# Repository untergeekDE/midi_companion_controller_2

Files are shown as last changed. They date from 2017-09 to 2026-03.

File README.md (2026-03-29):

# MIDI Companion Controller V3.0

A MIDI companion controller with two analog wheels (pitch bend + mod wheel), two buttons, a footswitch, two LEDs, and a 128x64 OLED display. Runs on a Raspberry Pi Pico 2 (RP2350) with CircuitPython 10.x.

## Features

- **Two analog wheels**: Pitch bend (centered) and modulation (CC1)
- **Two buttons + footswitch**: Configurable as CC, NoteOn/Off, Aftertouch, or Off
- **OLED display**: Shows MIDI channel, wheel values, firmware version
- **DIN MIDI In/Out**: Standard 5-pin DIN via UART + optocoupler circuit
- **USB MIDI**: Appears as a USB MIDI device to a connected computer/DAW
- **USB Host** (optional): MAX3421E breakout for connecting USB MIDI devices (e.g., Launchpad)
- **MIDI merge engine**: Routes messages between all inputs and outputs with echo prevention
- **On-device menu**: Configure CC assignments, MIDI channel, thru, deadband, calibration
- **Watchdog**: Auto-resets if the main loop hangs (enabled after first successful iteration)

## Hardware

- **Board**: Raspberry Pi Pico 2 W (RP2350, CircuitPython 10.1.4)
- **Display**: SSD1306 128x64 I2C OLED at 0x3C
- **MIDI DIN**: Optocoupler circuit or Adafruit MIDI FeatherWing
- **USB Host**: Adafruit MAX3421E breakout (optional)

### Pin Assignments

| GPIO | Function | Notes |
|---|---|---|
| GP0 | Button A | Menu / navigation, INPUT_PULLUP |
| GP1 | Button B | Confirm / set, INPUT_PULLUP |
| GP2 | LED 1 | MIDI input activity |
| GP3 | LED 2 | MIDI output activity |
| GP4 | UART TX | DIN MIDI Out, 31250 baud |
| GP5 | UART RX | DIN MIDI In, 31250 baud |
| GP13 | Footswitch | 1/4" jack, INPUT_PULLUP |
| GP14 | USB Host INT | MAX3421E (optional) |
| GP16 | SPI MISO | MAX3421E (optional) |
| GP18 | SPI CLK | MAX3421E (optional) |
| GP19 | SPI MOSI | MAX3421E (optional) |
| GP20 | I2C SDA | OLED |
| GP21 | I2C SCL | OLED |
| GP22 | USB Host CS | MAX3421E (optional) |
| GP26/A0 | Wheel A | Pitch bend (analog) |
| GP27/A1 | Wheel B | Modulation (analog) |

See [HARDWARE_PICO.md](HARDWARE_PICO.md) for detailed documentation.

## Installation

1. Install CircuitPython 10.x on the Pico 2
2. Copy `circuitpython/` contents to the CIRCUITPY drive
3. Install Adafruit libraries:
   ```bash
   pip install circup
   circup install adafruit_midi adafruit_debouncer adafruit_ticks adafruit_displayio_ssd1306 adafruit_display_text
   ```
4. For USB Host mode, also: `circup install adafruit_usb_host_midi max3421e`

## Developer Mode

Hold **Button A** (GP0) during power-on to enter dev mode. This keeps the CIRCUITPY drive writable from USB for editing files. In normal mode, CircuitPython owns the filesystem for writing config.json.

## Testing

Host-side integration tests communicate with the Pico over USB MIDI and serial:

```bash
pip install -r tests/requirements.txt
# Automated tests (device connected, normal mode):
MIDI_DEVICE_NAME=CircuitPython pytest tests/ -v --ignore=tests/test_wheels_buttons.py
# Interactive hardware test:
MIDI_DEVICE_NAME=CircuitPython python3 tests/test_hardware.py
```

See [tests/README.md](tests/README.md) for details.

## Known Issues and Status (2026-03-29)

### Verified Working
- Button A (GP0) and Button B (GP1) — confirmed via GPIO probe
- LED 1 (GP2) and LED 2 (GP3) — confirmed via LED test
- OLED display — working with CP10 `i2cdisplaybus.I2CDisplayBus`, rotation=0
- USB MIDI device — enumeration, send, receive all working
- DIN UART loopback — raw bytes sent on GP4/TX received on GP5/RX through DIN connectors (optocoupler circuit functional)
- Config persistence — load, save, validation, corrupt detection all working
- Wheel B (mod wheel) — sends CC1, values 0-127, display shows decimal
- Wheel A (pitch bend) — sends PitchBend, calibrated, display shows signed values

### Known Issues

| Issue | Status | Details |
|---|---|---|
| **DIN MIDI not reaching external synth** | **Open** | UART loopback through DIN connectors works (raw bytes verified). USB→DIN routing via merge engine sends data, but external synthesizer does not respond. Possible causes: cable pin assignment (DIN-5 pins 4/5), signal level/polarity through optocoupler, or synth-specific issue. Needs oscilloscope verification. |
| **Wheel B ADC jitter** | **Open** | Mod wheel oscillates ±2 values at rest (e.g., 44-46), causing continuous CC output and LED B staying on. Root cause: ADC noise on the potentiometer. Mitigations: increase deadband, add 100nF capacitor across pot, or implement hysteresis filter in software. |
| **Watchdog crash-loop** | **Fixed** | Watchdog now only activates after the first fully successful loop iteration. If code.py crashes on startup, the device stays at the REPL instead of resetting endlessly. |
| **CircuitPython 10 API changes** | **Fixed** | `displayio.I2CDisplay` → `i2cdisplaybus.I2CDisplayBus`, `watchdog.WatchdogMode` → `watchdog.WatchDogMode`, `PitchBend` expects unsigned 0-16383. |

### Hardware Test Results

```
Buttons:  GP0 (A) ✓  GP1 (B) ✓
LEDs:     GP2 ✓  GP3 ✓
UART:     GP4 TX → DIN OUT → DIN IN → GP5 RX: loopback ✓
Display:  SSD1306 I2C 0x3C: ✓ (rotation=0)
USB MIDI: enumeration ✓, send ✓, receive ✓
DIN→Synth: ✗ (needs investigation)
```

## Project Structure

```
circuitpython/
  boot.py              # Filesystem + USB setup
  code.py              # Main loop (v2.0.0)
  config.json          # Persistent config (JSON)
  lib/
    config.py          # ConfigManager with validation
    menu.py            # On-device config menu
    calibration.py     # Wheel calibration (30s timeout)
    midi_merge.py      # N→M merge with echo prevention
    hardware/
      pins.py          # Pin definitions (single source of truth)
      wheels.py        # Analog wheel with deadband
      buttons.py       # Debounced buttons with double-click
      leds.py          # LEDs with 50ms min on-time
      display.py       # SSD1306 OLED via displayio
      midi_uart.py     # DIN MIDI via UART
      midi_usb_device.py  # Native USB MIDI
      midi_usb_host.py    # MAX3421E USB Host (optional)
tests/
  conftest.py          # MIDI + serial REPL fixtures
  test_hardware.py     # Interactive hardware diagnostic
  test_midi_device.py  # USB MIDI enumeration tests
  test_config.py       # Config persistence tests
  test_error_recovery.py  # Corrupt config, MIDI flood
  test_wheels_buttons.py  # Manual input tests
```

## History

- **V1.0**: Arduino + DangerShield (original prototype)
- **V2.0**: Teensy 3.2 + custom hardware (`src/main.cpp` — legacy, see [BUGLIST_TEENSY.md](BUGLIST_TEENSY.md))
- **V3.0**: Raspberry Pi Pico 2 + CircuitPython 10 (this version)

## License

CC-BY — untergeek.de

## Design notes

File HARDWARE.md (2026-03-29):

# Hardware Documentation

MIDI companion controller with two analog wheels (pitch bend + mod wheel), two buttons, a footswitch, two LEDs, and a 128x64 OLED display. Two hardware implementations exist.

See the implementation-specific files:

- [HARDWARE_TEENSY.md](HARDWARE_TEENSY.md) — Teensy 3.2 (`src/main.cpp`)
- [HARDWARE_PICO.md](HARDWARE_PICO.md) — Raspberry Pi Pico 2 (`circuitpython/`)

Fritzing schematic (Teensy): `midicompanion2-0.fzz`

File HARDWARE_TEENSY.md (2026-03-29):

# Hardware Documentation — Teensy 3.2

Implementation: `src/main.cpp`

## Board
- **MCU**: Teensy 3.2 (MK20DX256, ARM Cortex-M4, 72 MHz)
- **USB**: Native USB MIDI (via Teensyduino)
- **ADC**: 10-bit (0-1023)

## Pin Assignments

| Pin | Type | Function | Notes |
|-----|---|---|---|
| A22 | Analog | Wheel A (Pitch Bend) | Left wheel |
| A23 | Analog | Wheel B (Modulation) | Right wheel |
| D17 | Digital | Button A | Menu / navigation, INPUT_PULLUP |
| D15 | Digital | Button B | Confirm / set, INPUT_PULLUP |
| D13 | Digital | Button C (Footswitch) | 1/4" jack, INPUT_PULLUP |
| D16 | Digital | LED 1 | MIDI input activity |
| D14 | Digital | LED 2 | MIDI output activity |
| D4 | Digital | OLED Reset | SSD1306 reset pin |
| Serial1 TX/RX | UART | DIN MIDI In/Out | 31,250 baud |
| I2C (Wire) | I2C | OLED Display | SSD1306 128x64 |

## Components
- **Display**: SSD1306 128x64 I2C OLED (custom `OLED_I2C_128x64_Monochrome` library)
- **MIDI**: DIN-5 In/Out via Serial1 UART at 31,250 baud
- **Buttons**: Momentary pushbuttons, active low (INPUT_PULLUP)
- **Footswitch**: 1/4" TRS jack, active low (INPUT_PULLUP)
- **LEDs**: Standard LEDs, HIGH = on
- **Wheels**: Linear potentiometers, ~256 ADC count range

## Wheel Calibration Defaults
| Parameter | Wheel A (Pitch) | Wheel B (Mod) |
|---|---|---|
| Center | 658 | 909 |
| Delta | 517 | 700 |

## EEPROM Memory Map (32 bytes)

| Byte(s) | Purpose | Default |
|---|---|---|
| 0 | Checksum (additive sum) | — |
| 1 | Wheel A CC (0x80 = pitch bend) | 0x80 |
| 2 | Wheel B CC (0x80 = pitch bend) | 1 (CC1 Mod) |
| 3 | Button A CC (0x80 = aftertouch) | 64 (Sustain) |
| 4 | Button B CC (0x80 = aftertouch) | 0x80 |
| 5 | Button C (Footswitch) CC | 64 (Sustain) — code default; `#define CCBUTTON_C 66` is unused |
| 6-7 | Wheel A delta (calibration) | 517 |
| 8-9 | Wheel A center | 658 |
| 10-11 | Wheel A Hi (unused) | 256 |
| 12-13 | Wheel B delta | 700 |
| 14-15 | Wheel B center | 909 |
| 16-17 | Wheel B Hi (unused) | 256 |
| 18 | TX MIDI channel (1-16) | 1 |
| 19 | Aftertouch default value | 64 |
| 20 | MIDI Thru on/off | 0 |
| 21 | Deadband width (0-63) | 10 |
| 22-31 | Unused | 0 |

## Schematic

Fritzing file: `midicompanion2-0.fzz`

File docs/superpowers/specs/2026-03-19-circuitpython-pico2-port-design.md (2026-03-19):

# MIDI Companion Controller 2 — CircuitPython Port for Raspberry Pi Pico 2

## Overview

Port of the Teensy 3.2-based MIDI companion controller to Raspberry Pi Pico 2 (RP2350) running CircuitPython. The controller merges MIDI input from a Novation Launchpad Pro 3 (via USB Host) and local controls (wheels, buttons, footswitch) with optional DIN MIDI Thru, outputting a merged MIDI stream over DIN MIDI to a Roland SE-02 synthesizer.

### Key Changes from Original

- Teensy 3.2 → Raspberry Pi Pico 2 (RP2350)
- C++ (Arduino/Teensyduino) → CircuitPython 9.x
- Single 790-line file → modular library with HAL + feature modules
- EEPROM with checksum → JSON config file on CIRCUITPY flash
- Custom OLED library → standard adafruit_displayio_ssd1306
- USB-MIDI device output → removed (DIN-only output). `boot.py` disables USB MIDI device and USB HID to free the USB stack. The Pico does not appear as a MIDI device to a connected computer.
- New: USB Host input via MAX3421E SPI breakout for Launchpad Pro 3
- Deliberate behavior change: channel auto-tracking from DIN input is removed. The controller always sends on the configured `tx_channel`. (The original Teensy code would adopt the channel of any incoming MIDI message.)

## Signal Flow

```
┌─────────────────────┐     ┌──────────────────┐
│  Launchpad Pro 3    │     │  DIN MIDI In      │
│  (USB Host/MAX3421E)│     │  (UART RX)        │
└────────┬────────────┘     └────────┬───────────┘
         │ all MIDI data              │ any MIDI
         │ (no filtering)            │ data
         ▼                           ▼
    ┌─────────────────────────────────────┐
    │            MidiMerge                │
    │  ┌───────────────────────────┐      │
    │  │ inject() ← local events  │      │
    │  │  · Pitch Bend (Wheel A)  │      │
    │  │  · Mod Wheel (Wheel B)   │      │
    │  │  · CC/ATO (Buttons)      │      │
    │  └───────────────────────────┘      │
    └────────────────┬────────────────────┘
                     │ merged
                     │ MIDI stream
                     ▼
            ┌─────────────────┐
            │  DIN MIDI Out   │
            │  (UART TX)      │
            │  → Roland SE-02 │
            └─────────────────┘
```

## Project Structure

```
circuitpython/
  boot.py                       # Runs before code.py: remounts filesystem writable, disables USB MIDI/HID
  code.py                       # Entry point: setup + main loop (wiring only, no logic)
  config.json                   # Persisted configuration on CIRCUITPY flash
  lib/
    hardware/
      pins.py                   # Pin definitions as central constants (only place GPIOs are defined)
      wheels.py                 # AnalogWheel: read, calibration, deadband
      buttons.py                # DebouncedButton: debounce, fell/rose, double-click detection
      leds.py                   # StatusLED: on/off
      display.py                # OledDisplay: SSD1306 via displayio
      midi_uart.py              # UartMidi: DIN MIDI In + Out over UART
      midi_usb_host.py          # UsbHostMidi: MAX3421E via adafruit_usb_host_midi
    midi_merge.py               # MidiMerge: N inputs merged onto M outputs
    config.py                   # ConfigManager: JSON read/write, defaults, validation
    menu.py                     # OnDeviceMenu: menu structure, navigation, value editing
    calibration.py              # WheelCalibration: interactive calibration, saves to config
```

The existing Teensy version remains unchanged in `src/`.

## Hardware Modules

### pins.py

Pure constants file. All GPIO assignments in one place. All other modules import from here. Also defines SPI pins for the MAX3421E.

### wheels.py — AnalogWheel

```python
wheel = AnalogWheel(pin, mode="pitch_bend", deadband=10)
wheel.calibrate(center=658, delta=517)
value = wheel.read()  # → int: -8192..8191 (pitch_bend) or 0..127 (cc)
wheel.changed         # → bool: True if value changed since last read
wheel.value           # → int: last read value
```

- Wraps `analogio.AnalogIn` with calibration offset and deadband logic.
- Mode (`pitch_bend` vs `cc`) determines centered (signed) or uncentered (unsigned) reading.
- **Pitch bend mode** returns 14-bit values (-8192..8191) as expected by `adafruit_midi.PitchBend`. The original code reads -128..127 and multiplies by 64; this module does the scaling internally.
- **CC mode** returns 7-bit values (0..127).
- Calibration uses `center` for pitch bend mode (centered wheel) and `delta` for CC mode (uncentered wheel), matching the original behavior (see original lines 725-726).
- `deadband` is a global setting shared by both wheels (loaded from `config.deadband`).
- Same algorithm as original `readWheel()`, encapsulated as a class.

### buttons.py — DebouncedButton

```python
btn = DebouncedButton(pin, debounce_ms=10, double_click_ms=250)
btn.update()
btn.fell              # → bool: just pressed
btn.rose              # → bool: just released
btn.double_click      # → bool: double-click detected
```

- Uses `adafruit_debouncer` instead of Bounce2.
- Double-click detection built in (timestamp-based, like original).
- `fell` = button pressed (active low with INPUT_PULLUP), `rose` = button released. All buttons use the same polarity convention. The main loop determines what MIDI value to send on fell vs. rose (e.g., CC 127 on fell, CC 0 on rose).

### leds.py — StatusLED

```python
led = StatusLED(pin)
led.on()
led.off()
```

- Minimal wrapper around `digitalio.DigitalInOut`.
- LED1 = MIDI input activity, LED2 = MIDI output activity.

### display.py — OledDisplay

```python
disp = OledDisplay(i2c)
disp.show_workscreen(channel=1, wheel_a=0, wheel_b=0)
disp.show_text(row, col, text, inverted=False)
disp.show_hex(row, col, value)
disp.clear()
disp.update_values(wheel_a=0, wheel_b=0)
```

- Uses `displayio` + `adafruit_displayio_ssd1306` + `adafruit_display_text`.
- Abstracts workscreen, menu, and calibration screen rendering.
- Font size handling internal (replaces global `fontsize` variable from original).
- Display is rotated 180 degrees (matching original `oled.rotateDisplay180()`) — configured in `displayio` initialization.

### midi_uart.py — UartMidi

```python
midi = UartMidi(uart_tx_pin, uart_rx_pin)
msg = midi.receive()                        # → adafruit_midi message or None
midi.send(msg)                              # Send any MIDI message
midi.send_cc(cc, value, channel)
midi.send_pitch_bend(value, channel)
midi.send_aftertouch(value, channel)
```

- Uses `adafruit_midi` over `busio.UART` at 31250 baud.
- Shared message format with `UsbHostMidi` (both use `adafruit_midi` message types).

### midi_usb_host.py — UsbHostMidi

```python
usb_midi = UsbHostMidi(spi, cs_pin)
msg = usb_midi.receive()  # → adafruit_midi message or None
```

- MAX3421E over SPI via `adafruit_max3421e` + `adafruit_usb_host_midi`.
- Same message interface as `UartMidi`.
- Receive only (Launchpad sends to controller).
- **Hot-plug handling:** `receive()` returns `None` if no device is connected. The module handles enumeration failures and disconnection gracefully — no crash, no error on display, just no input from that source. On reconnection, the device is re-enumerated automatically.
- No device filtering: any USB MIDI device is accepted, not just the Launchpad.

## MidiMerge

```python
merge = MidiMerge(
    inputs=[uart_midi_in, usb_host_midi],
    outputs=[uart_midi_out],
    thru_enabled=False
)
merge.process()           # Read all inputs, forward to outputs
merge.inject(msg)         # Inject local messages (wheels/buttons)
merge.had_input           # → bool: True if any input was received this cycle
```

### Merge Rules

- **USB Host input** (Launchpad): always forwarded to outputs unmodified. No filtering, no channel remapping.
- **DIN MIDI input:** only forwarded when `thru_enabled` is True. When `thru_enabled` is False, DIN input is ignored (not merged). This matches the original behavior where MIDI Thru is a configurable on/off toggle.
- Local events (wheels, buttons) are injected via `inject()` and always sent on `tx_channel`.
- `process()` called once per main loop iteration.
- Order per loop: read inputs → inject local events → send all.

## Configuration System

### config.json

```json
{
  "midi": {
    "tx_channel": 1,
    "thru_enabled": false
  },
  "wheel_a": {
    "mode": "pitch_bend",
    "cc_number": null,
    "calibration": {
      "delta": 517,
      "center": 658
    }
  },
  "wheel_b": {
    "mode": "cc",
    "cc_number": 1,
    "calibration": {
      "delta": 700,
      "center": 909
    }
  },
  "button_a": {
    "mode": "cc",
    "cc_number": 64
  },
  "button_b": {
    "mode": "aftertouch",
    "aftertouch_value": 64
  },
  "footswitch": {
    "mode": "cc",
    "cc_number": 66
  },
  "deadband": 10
}
```

### ConfigManager

```python
config = ConfigManager("config.json")
config.load()                          # Read file, fall back to built-in defaults
config.save()                          # Write current state to file
config.get("midi.tx_channel")          # → value
config.set("midi.tx_channel", 2)       # Update in memory
```

- Falls back to built-in defaults when file is missing or corrupt.
- Validates value ranges on load (channel 1-16, CC 0-127, etc.).
- Replaces EEPROM+checksum system entirely.
- **Filesystem write access:** `boot.py` remounts the CIRCUITPY filesystem as writable by CircuitPython code (`storage.remount("/", readonly=False)`). Side effect: the drive becomes read-only when connected to a computer via USB. To edit `config.json` or `code.py` from a PC, hold a designated button during boot to skip the remount (keeping the filesystem writable by USB instead).

### Interaction with On-Device Menu

1. On startup: `config.load()` reads the file.
2. Menu changes: `config.set()` updates values in memory.
3. On menu exit: `config.save()` writes everything back to JSON.

## Menu System

### OnDeviceMenu

```python
menu = OnDeviceMenu(display, config, wheels, buttons)
menu.enter()    # Blocks until menu is exited
```

**Trigger:** Double-click on Button A.

**Note:** Menu and calibration are blocking — MIDI processing stops while the menu is active. This matches the original behavior and is a deliberate choice (menu interaction is brief and infrequent).

**Navigation** (same as original):
- Button A: next option
- Button B: set/confirm value
- Wheel B: scroll value
- "X" top right: exit menu

**Menu Options:**

| Option | Range | Description |
|---|---|---|
| Wheel A | CC 0-127 / PWH | CC number or pitch bend |
| Wheel B | CC 0-127 / PWH | CC number or pitch bend |
| Button A | CC 0-127 / ATO | CC number or aftertouch |
| Button B | CC 0-127 / ATO | CC number or aftertouch |
| Footswitch | CC 0-127 / ATO | CC number or aftertouch |
| TX Channel | 1-16 | MIDI transmit channel |
| Thru | ON/OFF | DIN MIDI Thru |
| ATO Value | 0-127 | Aftertouch default value |
| Deadband | 0-63 | Deadband width |
| Calibrate | GO | Starts calibration routine |

## Calibration

### WheelCalibration

```python
cal = WheelCalibration(display, wheels, buttons, config)
cal.run()       # Blocks: shows instructions, waits for button, measures, saves
```

**Sequence** (same as original):
1. Display shows "Release Pitch Wheel / Return Mod Wheel to zero / Press button"
2. User presses Button B
3. Read current analog values as center/delta
4. Write values to ConfigManager
5. Show confirmation, wait for button press
6. Return to menu

## Main Loop (code.py)

`code.py` contains only wiring and the main loop — no business logic. All domain logic lives in the modules.

```python
# 1. SETUP
config = ConfigManager("config.json")
config.load()

# Initialize all hardware via pin constants
# Initialize MidiMerge with uart_midi + usb_host_midi inputs, uart_midi output
# Initialize OnDeviceMenu
# Show workscreen

# 2. MAIN LOOP
while True:
    # Update all buttons
    # Check for double-click → enter menu
    # merge.process() — read all MIDI inputs, forward
    # LED1 blink on MIDI input
    # Read wheels, inject changed values via merge.inject()
    # Read buttons, inject fell/rose events via merge.inject()
    # LED2 blink on MIDI output
    # Update display (only on value changes)
    # Turn off LEDs at end of loop
```

The loop is synchronous — CircuitPython on RP2350 is fast enough for real-time MIDI.

## Dependencies

### Adafruit CircuitPython Libraries (from Bundle)

| Library | Purpose |
|---|---|
| `adafruit_midi` | MIDI message types + UART MIDI |
| `adafruit_usb_host_midi` | USB Host MIDI via MAX3421E |
| `adafruit_max3421e` | MAX3421E SPI driver |
| `adafruit_debouncer` | Button debouncing |
| `adafruit_displayio_ssd1306` | SSD1306 OLED driver |
| `adafruit_display_text` | Text rendering on displayio |
| `adafruit_bitmap_font` | Font sizes (optional) |

### Built-in CircuitPython Modules

| Module | Purpose |
|---|---|
| `board`, `digitalio`, `analogio` | GPIO |
| `busio` | I2C, SPI, UART |
| `displayio` | Display framework |
| `json` | Config file parsing |
| `time` | Timing (double-click, LED blink) |
| `usb_host` | USB Host base functionality |

### Target Platform

- **Board:** Raspberry Pi Pico 2 or Pico 2 W (RP2350)
- **CircuitPython:** 9.x (stable for RP2350, USB Host support)
- **USB Host Hardware:** Adafruit MAX3421E USB Host Breakout (SPI)

### Additional Hardware

- SSD1306 128x64 I2C OLED (same as original)
- MIDI DIN In/Out circuit — either:
  - Custom optocoupler circuit (same as original), OR
  - Adafruit MIDI FeatherWing (plug-and-play alternative, provides DIN In + Out via UART)
- Potentiometers/wheels, buttons, footswitch, LEDs (same as original)

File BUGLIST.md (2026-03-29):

# Bug List & Known Weaknesses

See the implementation-specific files:

- [BUGLIST_TEENSY.md](BUGLIST_TEENSY.md) — Teensy 3.2 bugs and weaknesses
- [BUGLIST_PICO.md](BUGLIST_PICO.md) — CircuitPython / Pico 2 bugs and weaknesses

Last reviewed: 2026-03-29, iteration 7 (final)

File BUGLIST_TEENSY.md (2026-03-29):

# Bug List — Teensy 3.2 (`src/main.cpp`)

Last reviewed: 2026-03-29, iteration 5 (Teensy review complete — further iterations focused on Pico only)

## Bugs

| # | Severity | Location | Description |
|---|---|---|---|
| T1 | **Critical** | Lines 743, 771 | **CC modulo is wrong**: `EEPROM[1] % 0x7f` uses 127, not 128. CC value 127 wraps to 0. Should be `% 128` or bounds-check to 0-127. |
| T2 | **Critical** | Lines 656, 688, 708 | **Aftertouch never triggers**: `EEPROM[3] > 0x80` should be `>= 0x80`. The aftertouch sentinel is 0x80 (128), but `128 > 128` is false. The aftertouch branch is unreachable for all three buttons. Instead, CC 128 is sent (out of MIDI spec). |
| T3 | **High** | Lines 695, 715 | **Button B/C CC polarity inverted**: Button A uses `!button1.read() * 127` (pressed=127, released=0), but buttons B and C use `button2.read() ? 127 : 0` (pressed=0, released=127). CC messages are backwards — sustain activates on release, not press. |
| T4 | **Medium** | Line 737 | **Pitch bend scaling short of full range**: `value * 64` gives max 127x64=8128, but MIDI pitch bend max is 8191. Positive range is ~0.8% short of full scale. |

## Weaknesses

| # | Severity | Location | Description |
|---|---|---|---|
| T5 | Medium | Lines 636-647 | **Auto-adopts incoming MIDI channel**: `MidiTxCh = MidiRxCh` silently changes the TX channel to match any incoming message. |
| T6 | Medium | Lines 612-761 | **LED blinks invisible**: LEDs turn on/off within a single loop iteration (<2ms). No minimum on-time. |
| T7 | Medium | Line 417 | **Menu has no timeout**: `for(;;)` blocks indefinitely. No watchdog or auto-exit. |
| T8 | Medium | Lines 378-379 | **Calibration assumes ~256 ADC range**: `center = delta + 128` hardcoded. |
| T9 | Medium | Lines 653, 685, 705 | **Buttons send CC on every update**: RefreshFlag causes continuous CC sends, not just on edges. |
| T10 | Low | Line 500 | **Menu calls itself recursively**: `calibrate()` -> `menu()` recursive. Stack grows per calibration. |
| T11 | Low | Line 280 | **Footswitch default CC mismatch**: `nvrInits[5] = 64` but `#define CCBUTTON_C 66` unused. |
| T12 | Low | Lines 252-264 | **Deadband asymmetric**: Pitch wheel symmetric, CC wheel low-end only. Intentional but undocumented. |
| T13 | Low | EEPROM byte 0 | **Weak checksum**: Additive sum mod 256. No CRC. |
| T14 | Low | Lines 619-625 | **MIDI Thru UART only**: USB thru block empty. USB input never forwarded. |
| T15 | Low | EEPROM 10-11, 16-17 | **Dead EEPROM entries**: WheelA/B Hi values written but never read. |
| T16 | Low | Line 591 | **No input channel filtering**: MIDI_CHANNEL_OMNI only. |
| T17 | Low | Main loop | **USB MIDI input never read**: `midiB.read()` never called. Output-only. |
| T18 | Low | Line 79 | **USB uses serial transport**: `SerialUSB` via 47 Effects library, not Teensyduino's native `usbMIDI`. |
| T19 | Info | Lines 214-215 | **EEPROM display access**: Low risk — protected by nvrInit on first boot. |

## Design Concerns

| # | Area | Description |
|---|---|---|
| D1 | Menu blocks main loop | No MIDI processing during menu interaction. |
| D2 | No watchdog | Software hangs require power cycle. |
| D3 | Synchronous MIDI output | Slow DIN output can delay USB timing. |
| D4 | Single-file architecture | 788-line monolithic file. |
| D5 | `#include <SPI.h>` unused | SPI library included but only I2C (Wire) used. |

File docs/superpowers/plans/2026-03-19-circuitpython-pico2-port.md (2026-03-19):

# CircuitPython Pico 2 Port — Implementation Plan

> **For agentic workers:** REQUIRED SUB-SKILL: Use superpowers:subagent-driven-development (recommended) or superpowers:executing-plans to implement this plan task-by-task. Steps use checkbox (`- [ ]`) syntax for tracking.

**Goal:** Port the Teensy 3.2 MIDI companion controller to Raspberry Pi Pico 2 running CircuitPython, with a modular architecture, JSON-based config, USB Host MIDI input, and DIN MIDI output.

**Architecture:** HAL layer (`hardware/`) wraps each physical component as a class. Feature modules (`config.py`, `midi_merge.py`, `menu.py`, `calibration.py`) contain all business logic. `code.py` wires everything together with zero logic. `boot.py` handles filesystem and USB setup.

**Tech Stack:** CircuitPython 9.x, adafruit_midi, adafruit_max3421e, adafruit_usb_host_midi, adafruit_debouncer, adafruit_displayio_ssd1306, adafruit_display_text

**Spec:** `docs/superpowers/specs/2026-03-19-circuitpython-pico2-port-design.md`

**Testing approach:** This is an embedded microcontroller project — no pytest. Each task includes an on-device verification script or REPL commands to confirm the module works on real hardware before moving on.

---

## File Map

| File | Responsibility | Created in Task |
|---|---|---|
| `circuitpython/boot.py` | Filesystem remount, disable USB MIDI/HID, dev-mode button | 1 |
| `circuitpython/lib/hardware/pins.py` | All GPIO pin constants | 1 |
| `circuitpython/lib/config.py` | JSON config read/write/defaults/validation | 2 |
| `circuitpython/config.json` | Default configuration file | 2 |
| `circuitpython/lib/hardware/leds.py` | StatusLED class | 3 |
| `circuitpython/lib/hardware/buttons.py` | DebouncedButton with double-click | 4 |
| `circuitpython/lib/hardware/wheels.py` | AnalogWheel with calibration + deadband | 5 |
| `circuitpython/lib/hardware/display.py` | OledDisplay via displayio + SSD1306 | 6 |
| `circuitpython/lib/hardware/midi_uart.py` | UartMidi DIN MIDI In/Out | 7 |
| `circuitpython/lib/hardware/midi_usb_host.py` | UsbHostMidi via MAX3421E | 8 |
| `circuitpython/lib/midi_merge.py` | MidiMerge: N inputs → M outputs | 9 |
| `circuitpython/lib/calibration.py` | WheelCalibration interactive routine | 10 |
| `circuitpython/lib/menu.py` | OnDeviceMenu with all config options | 11 |
| `circuitpython/code.py` | Main entry point: setup + loop | 12 |

---

### Task 1: boot.py and pins.py — Foundation

**Files:**
- Create: `circuitpython/boot.py`
- Create: `circuitpython/lib/hardware/__init__.py`
- Create: `circuitpython/lib/hardware/pins.py`
- Create: `circuitpython/lib/__init__.py`

- [ ] **Step 1: Create directory structure**

```bash
mkdir -p circuitpython/lib/hardware
```

- [ ] **Step 2: Write `boot.py`**

Create `circuitpython/boot.py`:

```python
# boot.py — Runs before code.py on every boot.
#
# Responsibilities:
# 1. Remount the CIRCUITPY filesystem as writable by CircuitPython code,
#    so that ConfigManager can save config.json. Side effect: the drive
#    becomes read-only when connected to a computer via USB.
# 2. Disable USB MIDI device and USB HID — the Pico should not appear
#    as a MIDI device or HID to a connected computer.
# 3. Dev-mode escape hatch: if Button A (the designated button) is held
#    during boot, skip the remount so the filesystem stays writable by
#    USB (for editing code/config from a PC).

import board
import digitalio
import storage
import usb_midi
import usb_hid

# Check if Button A is held during boot (dev-mode escape hatch).
# Button A is on the pin defined in pins.py — we hardcode it here because
# pins.py hasn't been imported yet (boot.py runs before code.py).
# Pin must match hardware.pins.BUTTON_A.
dev_mode_pin = digitalio.DigitalInOut(board.GP17)
dev_mode_pin.direction = digitalio.Direction.INPUT
dev_mode_pin.pull = digitalio.Pull.UP

dev_mode = not dev_mode_pin.value  # Active low: pressed = False = dev_mode True
dev_mode_pin.deinit()

if not dev_mode:
    # Normal operation: filesystem writable by CircuitPython, read-only to USB host.
    storage.remount("/", readonly=False)

# Always disable USB MIDI device and USB HID — we use DIN MIDI only for output,
# and USB Host (MAX3421E) for input. The native USB port is power + CIRCUITPY only.
usb_midi.disable()
usb_hid.disable()
```

- [ ] **Step 3: Write `pins.py`**

Create `circuitpython/lib/hardware/pins.py`:

```python
# pins.py — Central pin definitions for the MIDI Companion Controller 2.
#
# This is the ONLY file where GPIO pin numbers are defined. All other modules
# import from here. If you rewire the hardware, change ONLY this file.
#
# Pin assignments assume a Raspberry Pi Pico 2 (RP2350).
# Adjust these if using a different board or wiring.

import board

# --- Analog Wheels ---
# Wheel A: left wheel, typically pitch bend
WHEEL_A = board.A0
# Wheel B: right wheel, typically mod wheel (CC1)
WHEEL_B = board.A1

# --- Buttons (active low, INPUT_PULLUP) ---
# Button A: left button (also triggers menu on double-click)
BUTTON_A = board.GP17
# Button B: right button (confirm/set in menu)
BUTTON_B = board.GP15
# Footswitch: external footswitch jack
FOOTSWITCH = board.GP13

# --- LEDs ---
# LED1: signals MIDI input activity
LED1 = board.GP2
# LED2: signals MIDI output activity (locally generated)
LED2 = board.GP3

# --- I2C (SSD1306 OLED Display) ---
I2C_SCL = board.GP21
I2C_SDA = board.GP20

# --- UART (DIN MIDI In/Out) ---
# Standard MIDI baud rate is 31250. The UART pins connect to the
# optocoupler circuit (or Adafruit MIDI FeatherWing).
UART_TX = board.GP4
UART_RX = board.GP5

# --- SPI (MAX3421E USB Host Breakout) ---
SPI_CLK = board.GP18
SPI_MOSI = board.GP19
SPI_MISO = board.GP16
USB_HOST_CS = board.GP22
USB_HOST_INT = board.GP26  # Interrupt pin for MAX3421E (optional but recommended)
```

- [ ] **Step 4: Create `__init__.py` files**

Create empty `circuitpython/lib/__init__.py` and `circuitpython/lib/hardware/__init__.py`.

- [ ] **Step 5: Verify on device**

Copy `circuitpython/` contents to CIRCUITPY drive. Open REPL (serial console) and run:

```python
from hardware import pins
print(pins.WHEEL_A)
print(pins.BUTTON_A)
print(pins.I2C_SCL)
# Should print pin objects without errors
```

- [ ] **Step 6: Commit**

```bash
git add circuitpython/boot.py circuitpython/lib/hardware/pins.py circuitpython/lib/__init__.py circuitpython/lib/hardware/__init__.py
git commit -m "feat: add boot.py and pins.py foundation for CircuitPython port"
```

---

### Task 2: ConfigManager — JSON Configuration

**Files:**
- Create: `circuitpython/lib/config.py`
- Create: `circuitpython/config.json`

- [ ] **Step 1: Write `config.py`**

Create `circuitpython/lib/config.py`:

```python
# config.py — JSON-based configuration manager.
#
# Replaces the Teensy's EEPROM+checksum system with a human-readable JSON file
# stored on the CIRCUITPY flash filesystem.
#
# Usage:
#     config = ConfigManager("config.json")
#     config.load()                       # Read file, or use defaults if missing/corrupt
#     value = config.get("midi.tx_channel")  # Dot-notation access
#     config.set("midi.tx_channel", 2)       # Update in memory
#     config.save()                          # Persist to flash
#
# The filesystem must be writable by CircuitPython (see boot.py).

import json

# Default configuration — used when config.json is missing or corrupt.
# These values match the original Teensy EEPROM defaults.
DEFAULTS = {
    "midi": {
        "tx_channel": 1,
        "thru_enabled": False
    },
    "wheel_a": {
        "mode": "pitch_bend",
        "cc_number": None,
        "calibration": {
            "delta": 517,
            "center": 658
        }
    },
    "wheel_b": {
        "mode": "cc",
        "cc_number": 1,
        "calibration": {
            "delta": 700,
            "center": 909
        }
    },
    "button_a": {
        "mode": "cc",
        "cc_number": 64
    },
    "button_b": {
        "mode": "aftertouch",
        "aftertouch_value": 64
    },
    "footswitch": {
        "mode": "cc",
        "cc_number": 66
    },
    "deadband": 10
}

# Validation rules: (min, max) inclusive. Only numeric fields need range checks.
# Keys use dot-notation matching config.get/set paths.
VALIDATION = {
    "midi.tx_channel": (1, 16),
    "wheel_a.cc_number": (0, 127),
    "wheel_b.cc_number": (0, 127),
    "button_a.cc_number": (0, 127),
    "button_b.cc_number": (0, 127),
    "button_b.aftertouch_value": (0, 127),
    "footswitch.cc_number": (0, 127),
    "deadband": (0, 63),
}

def _deep_copy(obj):
    """Deep copy a nested dict/list structure without the copy module."""
    if isinstance(obj, dict):
        return {k: _deep_copy(v) for k, v in obj.items()}
    if isinstance(obj, list):
        return [_deep_copy(item) for item in obj]
    return obj

class ConfigManager:
    """Manages reading, writing, and validating the JSON configuration file.

    Attributes:
        path: Filesystem path to the config.json file.
        data: The current configuration dictionary (in memory).
    """

    def __init__(self, path):
        self.path = path
        self.data = _deep_copy(DEFAULTS)

    def load(self):
        """Load configuration from the JSON file.

        Falls back to built-in defaults if the file is missing, empty,
        or contains invalid JSON. Merges loaded data over defaults so
        that any missing keys get default values.
        """
        try:
            with open(self.path, "r") as f:
                loaded = json.load(f)
            # Merge loaded values over a fresh copy of defaults.
            # This ensures new keys added in future firmware versions
            # get their default values even if the config file is old.
            self.data = _deep_copy(DEFAULTS)
            self._merge(self.data, loaded)
            self._validate()
        except (OSError, ValueError, KeyError):
            # File missing, empty, or corrupt — use defaults.
            self.data = _deep_copy(DEFAULTS)

    def save(self):
        """Write the current configuration to the JSON file.

        Requires the filesystem to be writable (see boot.py).
        Silently fails if the filesystem is read-only (dev mode).
        """
        try:
            with open(self.path, "w") as f:
                json.dump(self.data, f)
        except OSError:
            # Filesystem is read-only (dev mode) — silently skip.
            pass

    def get(self, dotpath):
        """Get a configuration value using dot-notation.

        Example: config.get("midi.tx_channel") returns 1.
        """
        keys = dotpath.split(".")
        obj = self.data
        for key in keys:
            obj = obj[key]
        return obj

    def set(self, dotpath, value):
        """Set a configuration value using dot-notation.

        Example: config.set("midi.tx_channel", 2).
        Updates in memory only — call save() to persist.
        """
        keys = dotpath.split(".")
        obj = self.data
        for key in keys[:-1]:
            obj = obj[key]
        obj[keys[-1]] = value

    def _merge(self, base, override):
        """Recursively merge override dict into base dict.

        Only updates keys that exist in both and have matching types,
        or adds keys from override that don't exist in base.
        """
        for key, value in override.items():
            if key in base and isinstance(base[key], dict) and isinstance(value, dict):
                self._merge(base[key], value)
            else:
                base[key] = value

    def _validate(self):
        """Clamp numeric values to their valid ranges.

        Values outside the valid range are clamped (not rejected),
        so the controller always boots with usable settings.
        """
        for dotpath, (lo, hi) in VALIDATION.items():
            try:
                val = self.get(dotpath)
                if val is not None and isinstance(val, (int, float)):
                    clamped = max(lo, min(hi, int(val)))
                    if clamped != val:
                        self.set(dotpath, clamped)
            except (KeyError, TypeError):
                pass
```

- [ ] **Step 2: Write default `config.json`**

Create `circuitpython/config.json`:

```json
{
    "midi": {
        "tx_channel": 1,
        "thru_enabled": false
    },
    "wheel_a": {
        "mode": "pitch_bend",
        "cc_number": null,
        "calibration": {
            "delta": 517,
            "center": 658
        }
    },
    "wheel_b": {
        "mode": "cc",
        "cc_number": 1,
        "calibration": {
            "delta": 700,
            "center": 909
        }
    },
    "button_a": {
        "mode": "cc",
        "cc_number": 64
    },
    "button_b": {
        "mode": "aftertouch",
        "aftertouch_value": 64
    },
    "footswitch": {
        "mode": "cc",
        "cc_number": 66
    },
    "deadband": 10
}
```

- [ ] **Step 3: Verify on device (or desktop Python)**

ConfigManager uses only `json` and file I/O — it can be tested on desktop Python:

```bash
cd circuitpython
python3 -c "
import sys; sys.path.insert(0, 'lib')
from config import ConfigManager

# Test defaults
c = ConfigManager('/tmp/test_config.json')
c.load()
assert c.get('midi.tx_channel') == 1
assert c.get('wheel_a.mode') == 'pitch_bend'
assert c.get('deadband') == 10

# Test set + save + reload
c.set('midi.tx_channel', 5)
c.save()
c2 = ConfigManager('/tmp/test_config.json')
c2.load()
assert c2.get('midi.tx_channel') == 5

# Test validation clamping
c.set('midi.tx_channel', 99)
c._validate()
assert c.get('midi.tx_channel') == 16

# Test corrupt file fallback
with open('/tmp/test_corrupt.json', 'w') as f:
    f.write('not json')
c3 = ConfigManager('/tmp/test_corrupt.json')
c3.load()
assert c3.get('midi.tx_channel') == 1  # fell back to defaults

print('All config tests passed.')
"
```

- [ ] **Step 4: Commit**

```bash
git add circuitpython/lib/config.py circuitpython/config.json
git commit -m "feat: add ConfigManager with JSON config, defaults, and validation"
```

---

### Task 3: StatusLED — Simplest Hardware Module

**Files:**
- Create: `circuitpython/lib/hardware/leds.py`

- [ ] **Step 1: Write `leds.py`**

Create `circuitpython/lib/hardware/leds.py`:

```python
# leds.py — Simple LED control for MIDI activity indicators.
#
# LED1 signals MIDI input activity (blinks when data arrives).
# LED2 signals MIDI output activity (blinks when controller sends data).
#
# Usage:
#     from hardware.leds import StatusLED
#     from hardware import pins
#     led = StatusLED(pins.LED1)
#     led.on()
#     led.off()

import digitalio

class StatusLED:
    """Controls a single status LED.

    The LED is driven as a simple digital output. Turn it on at the start
    of an event (MIDI in/out) and off at the end of the main loop cycle
    to create a brief activity blink.

    Args:
        pin: A board pin object (e.g., board.GP16).
    """

    def __init__(self, pin):
        self._led = digitalio.DigitalInOut(pin)
        self._led.direction = digitalio.Direction.OUTPUT
        self._led.value = False

    def on(self):
        """Turn the LED on."""
        self._led.value = True

    def off(self):
        """Turn the LED off."""
        self._led.value = False
```

- [ ] **Step 2: Verify on device**

Copy to CIRCUITPY. In REPL:

```python
from hardware.leds import StatusLED
from hardware import pins
led1 = StatusLED(pins.LED1)
led2 = StatusLED(pins.LED2)
led1.on()   # LED1 should light up
led2.on()   # LED2 should light up
import time; time.sleep(1)
led1.off()
led2.off()  # Both should turn off
```

- [ ] **Step 3: Commit**

```bash
git add circuitpython/lib/hardware/leds.py
git commit -m "feat: add StatusLED hardware module"
```

---

### Task 4: DebouncedButton — Button Input with Double-Click

**Files:**
- Create: `circuitpython/lib/hardware/buttons.py`

- [ ] **Step 1: Write `buttons.py`**

Create `circuitpython/lib/hardware/buttons.py`:

```python
# buttons.py — Debounced button input with double-click detection.
#
# Wraps adafruit_debouncer to provide clean button state with edge detection
# (fell/rose) and double-click detection via timestamp comparison.
#
# All buttons use INPUT_PULLUP, so pressed = LOW = False.
# "fell" means the signal fell from HIGH to LOW = button was just pressed.
# "rose" means the signal rose from LOW to HIGH = button was just released.
#
# Usage:
#     from hardware.buttons import DebouncedButton
#     from hardware import pins
#     btn = DebouncedButton(pins.BUTTON_A, double_click_ms=250)
#     while True:
#         btn.update()
#         if btn.fell:
#             print("pressed")
#         if btn.double_click:
#             print("double-click!")

import digitalio
import time
from adafruit_debouncer import Debouncer

class DebouncedButton:
    """A debounced button with edge detection and double-click support.

    Args:
        pin: A board pin object. Configured as INPUT_PULLUP internally.
        debounce_s: Debounce interval in seconds (default 0.01 = 10ms).
        double_click_ms: Time window in milliseconds for double-click
            detection (default 250). Set to 0 to disable double-click.
    """

    def __init__(self, pin, debounce_s=0.01, double_click_ms=250):
        # Set up the physical pin with pull-up resistor.
        self._pin = digitalio.DigitalInOut(pin)
        self._pin.direction = digitalio.Direction.INPUT
        self._pin.pull = digitalio.Pull.UP

        # Wrap in Debouncer for clean state transitions.
        self._debouncer = Debouncer(self._pin, interval=debounce_s)

        # Double-click detection state.
        self._double_click_ms = double_click_ms
        self._last_fell_time = 0  # monotonic_ns of last fell event
        self._double_click = False

    def update(self):
        """Sample the button and update state. Call once per main loop iteration.

        After calling update(), check .fell, .rose, and .double_click
        for the current cycle's events.
        """
        self._double_click = False
        self._debouncer.update()

        # Double-click detection: if we just got a fell event and the
        # previous fell was within the double-click window, flag it.
        if self._debouncer.fell and self._double_click_ms > 0:
            now = time.monotonic_ns()
            elapsed_ms = (now - self._last_fell_time) // 1_000_000
            if self._last_fell_time > 0 and elapsed_ms < self._double_click_ms:
                self._double_click = True
                self._last_fell_time = 0  # Reset so triple-click doesn't re-trigger.
            else:
                self._last_fell_time = now

    @property
    def fell(self):
        """True if the button was just pressed this cycle (HIGH→LOW transition)."""
        return self._debouncer.fell

    @property
    def rose(self):
        """True if the button was just released this cycle (LOW→HIGH transition)."""
        return self._debouncer.rose

    @property
    def double_click(self):
        """True if a double-click was detected this cycle."""
        return self._double_click

    @property
    def pressed(self):
        """True if the button is currently held down (steady state)."""
        return not self._debouncer.value  # Active low: pressed = False = True here.
```

- [ ] **Step 2: Verify on device**

In REPL:

```python
from hardware.buttons import DebouncedButton
from hardware import pins
btn = DebouncedButton(pins.BUTTON_A)
while True:
    btn.update()
    if btn.fell:
        print("PRESSED")
    if btn.rose:
        print("RELEASED")
    if btn.double_click:
        print("DOUBLE CLICK!")
```

Press Button A a few times — verify single press and double-click detection. Ctrl-C to exit.

- [ ] **Step 3: Commit**

```bash
git add circuitpython/lib/hardware/buttons.py
git commit -m "feat: add DebouncedButton with double-click detection"
```

---

### Task 5: AnalogWheel — Wheel Input with Calibration

**Files:**
- Create: `circuitpython/lib/hardware/wheels.py`

- [ ] **Step 1: Write `wheels.py`**

Create `circuitpython/lib/hardware/wheels.py`:

```python
# wheels.py — Analog wheel input with calibration and deadband.
#
# Reads a potentiometer/wheel via an analog input pin and converts the raw
# ADC value into a MIDI-ready value. Supports two modes:
#
# - "pitch_bend" (centered): Returns -8192..8191 (14-bit signed).
#   Uses the 'center' calibration value as zero reference.
#   Deadband is applied symmetrically around center.
#
# - "cc" (uncentered): Returns 0..127 (7-bit unsigned).
#   Uses the 'delta' calibration value as zero/low reference.
#   Deadband is applied above the zero position.
#
# The potentiometers in the wheel box have roughly a quarter of the full
# ADC range of travel, so we assume ~256 raw counts of usable range
# (out of the CircuitPython 16-bit ADC range of 0..65535).
#
# Usage:
#     from hardware.wheels import AnalogWheel
#     from hardware import pins
#     wheel = AnalogWheel(pins.WHEEL_A, mode="pitch_bend", deadband=10)
#     wheel.calibrate(center=658, delta=517)
#     value = wheel.read()

import analogio

# CircuitPython ADC returns 16-bit values (0..65535). The original Teensy
# code used 10-bit (0..1023). We scale down to 10-bit equivalent for
# compatibility with the original calibration values and algorithm.
_ADC_SHIFT = 6  # Right-shift 16-bit to 10-bit: 65535 >> 6 ≈ 1023

class AnalogWheel:
    """Reads an analog wheel/potentiometer with calibration and deadband.

    Args:
        pin: A board analog pin object (e.g., board.A0).
        mode: "pitch_bend" for centered wheel, "cc" for uncentered.
        deadband: Width of the dead zone around center/zero. Shared global
            value from config. Range 0..63.
    """

    def __init__(self, pin, mode="pitch_bend", deadband=10):
        self._adc = analogio.AnalogIn(pin)
        self.mode = mode
        self.deadband = deadband

        # Calibration values (raw 10-bit scale, matching original firmware).
        # Set via calibrate() or loaded from config.
        self._center = 512  # Mid-point for pitch bend mode.
        self._delta = 0     # Zero offset for CC mode.

        # State tracking for change detection.
        self._value = 0
        self._changed = False

    def calibrate(self, center=512, delta=0):
        """Set calibration values.

        Args:
            center: The raw ADC reading (10-bit scale) when the pitch bend
                wheel is at rest in the center position.
            delta: The raw ADC reading (10-bit scale) when the CC wheel
                is at its lowest/zero position.
        """
        self._center = center
        self._delta = delta

    def read(self):
        """Read the wheel and return a MIDI-ready value.

        Returns:
            int: -8192..8191 for pitch_bend mode, 0..127 for cc mode.
            Also updates .value and .changed properties.
        """
        # Read 16-bit ADC and scale down to 10-bit for algorithm compatibility.
        raw = self._adc.value >> _ADC_SHIFT

        if self.mode == "pitch_bend":
            new_value = self._read_centered(raw)
        else:
            new_value = self._read_uncentered(raw)

        self._changed = (new_value != self._value)
        self._value = new_value
        return new_value

    def _read_centered(self, raw):
        """Process a centered wheel (pitch bend).

        Subtracts the center calibration, applies deadband, clamps to
        -128..127 range, then scales to 14-bit (-8192..8191) for
        adafruit_midi PitchBend compatibility.

        This matches the original readWheel() with centered=true,
        plus the *64 scaling from the original main loop.
        """
        v = raw - self._center

        if v > 0:
            if v < self.deadband:
                v = 0
            else:
                v -= self.deadband
            if v > 127:
                v = 127
        elif v < 0:
            if v > -self.deadband:
                v = 0
            else:
                v += self.deadband
            if v < -128:
                v = -128

        # Scale from 8-bit (-128..127) to 14-bit (-8192..8191).
        return v * 64

    def _read_uncentered(self, raw):
        """Process an uncentered wheel (CC / mod wheel).

        Subtracts the delta calibration, applies deadband, clamps to
        0..255 range, then divides by 2 to get 0..127 for MIDI CC.

        This matches the original readWheel() with centered=false.
        """
        v = raw - self._delta

        if v < self.deadband:
            v = 0
        else:
            v -= self.deadband
        if v > 255:
            v = 255

        # Divide by 2 to get 7-bit range (0..127).
        return v >> 1

    @property
    def value(self):
        """The most recently read value."""
        return self._value

    @property
    def changed(self):
        """True if the value changed on the last read() call."""
        return self._changed
```

- [ ] **Step 2: Verify on device**

In REPL:

```python
from hardware.wheels import AnalogWheel
from hardware import pins
# Test with pitch bend wheel
wa = AnalogWheel(pins.WHEEL_A, mode="pitch_bend", deadband=10)
wa.calibrate(center=658, delta=517)
# Move wheel and read values
for _ in range(20):
    v = wa.read()
    print(f"pitch: {v:6d}  changed: {wa.changed}")
    import time; time.sleep(0.2)
```

Verify: center position reads ~0, moving wheel produces negative/positive values up to -8192/8191.

- [ ] **Step 3: Commit**

```bash
git add circuitpython/lib/hardware/wheels.py
git commit -m "feat: add AnalogWheel with calibration, deadband, and 14-bit pitch bend"
```

---

### Task 6: OledDisplay — SSD1306 Display

**Files:**
- Create: `circuitpython/lib/hardware/display.py`

- [ ] **Step 1: Write `display.py`**

Create `circuitpython/lib/hardware/display.py`:

```python
# display.py — SSD1306 128x64 OLED display abstraction.
#
# Provides a high-level interface for the three display screens:
# 1. Workscreen: shows MIDI channel and current wheel values (normal operation)
# 2. Menu screen: shows configuration options (via menu.py)
# 3. Calibration screen: shows calibration instructions (via calibration.py)
#
# Uses displayio + adafruit_displayio_ssd1306 for hardware driving,
# and adafruit_display_text for text rendering.
#
# The display is rotated 180 degrees to match the physical mounting
# of the original Teensy build.
#
# Usage:
#     import busio
#     from hardware import pins
#     from hardware.display import OledDisplay
#     i2c = busio.I2C(pins.I2C_SCL, pins.I2C_SDA)
#     disp = OledDisplay(i2c)
#     disp.show_workscreen(channel=1)
#     disp.update_values(wheel_a=0, wheel_b=64)

import displayio
import terminalio
from adafruit_displayio_ssd1306 import SSD1306
from adafruit_display_text import label

# Display dimensions.
_WIDTH = 128
_HEIGHT = 64

# Character dimensions for the built-in terminalio.FONT (6x14 at scale 1).
# We use this font at different scales for the workscreen.
_FONT = terminalio.FONT

class OledDisplay:
    """High-level interface to the SSD1306 128x64 OLED display.

    Args:
        i2c: A busio.I2C instance connected to the display.
        address: I2C address of the SSD1306 (default 0x3C).
        rotation: Display rotation in degrees (default 180 to match
            original hardware mounting).
    """

    def __init__(self, i2c, address=0x3C, rotation=180):
        # Release any previously held displays (important for soft-reboot).
        # Done here rather than at module level to avoid side effects on import.
        displayio.release_displays()
        display_bus = displayio.I2CDisplay(i2c, device_address=address)
        self._display = SSD1306(display_bus, width=_WIDTH, height=_HEIGHT,
                                rotation=rotation)

        # The root display group — everything drawn goes here.
        self._root = displayio.Group()
        self._display.root_group = self._root

        # Labels for the workscreen (created lazily in show_workscreen).
        self._ch_label = None
        self._wheel_a_label = None
        self._wheel_b_label = None

    def clear(self):
        """Clear the display by removing all elements."""
        while len(self._root) > 0:
            self._root.pop()

    def show_workscreen(self, channel=1):
        """Display the main operating screen: MIDI channel and wheel value placeholders.

        Args:
            channel: The current MIDI transmit channel (1-16).
        """
        self.clear()

        # Large channel display at the top.
        ch_text = f"Ch {channel:2d}"
        self._ch_label = label.Label(_FONT, text=ch_text, scale=2,
                                     x=0, y=10, color=0xFFFFFF)
        self._root.append(self._ch_label)

        # Wheel A label and value.
        lbl_a = label.Label(_FONT, text="A", scale=1, x=0, y=30, color=0xFFFFFF)
        self._root.append(lbl_a)
        self._wheel_a_label = label.Label(_FONT, text="  00", scale=2,
                                          x=24, y=30, color=0xFFFFFF)
        self._root.append(self._wheel_a_label)

        # Wheel B label and value.
        lbl_b = label.Label(_FONT, text="B", scale=1, x=0, y=50, color=0xFFFFFF)
        self._root.append(lbl_b)
        self._wheel_b_label = label.Label(_FONT, text="  00", scale=2,
                                          x=24, y=50, color=0xFFFFFF)
        self._root.append(self._wheel_b_label)

    def update_values(self, wheel_a=None, wheel_b=None):
        """Update the wheel value displays on the workscreen.

        Only redraws labels that have changed. Call this every loop iteration.

        Args:
            wheel_a: Current wheel A value (int), or None to skip update.
            wheel_b: Current wheel B value (int), or None to skip update.
        """
        if wheel_a is not None and self._wheel_a_label is not None:
            self._wheel_a_label.text = f"{wheel_a:4X}" if isinstance(wheel_a, int) else str(wheel_a)
        if wheel_b is not None and self._wheel_b_label is not None:
            self._wheel_b_label.text = f"{wheel_b:4X}" if isinstance(wheel_b, int) else str(wheel_b)

    def update_channel(self, channel):
        """Update the MIDI channel display on the workscreen."""
        if self._ch_label is not None:
            self._ch_label.text = f"Ch {channel:2d}"

    def show_text(self, x, y, text, scale=1, inverted=False):
        """Draw a text label at the given pixel position.

        Used by menu.py and calibration.py for arbitrary text placement.

        Args:
            x: X pixel coordinate.
            y: Y pixel coordinate.
            text: The string to display.
            scale: Font scale multiplier (1, 2, or 3).
            inverted: If True, draw black text on white background.
        """
        color = 0x000000 if inverted else 0xFFFFFF
        bg_color = 0xFFFFFF if inverted else 0x000000
        lbl = label.Label(_FONT, text=text, scale=scale,
                          x=x, y=y, color=color, background_color=bg_color)
        self._root.append(lbl)
        return lbl

    def remove_label(self, lbl):
        """Remove a previously added label from the display.

        Args:
            lbl: A label object returned by show_text().
        """
        try:
            self._root.remove(lbl)
        except ValueError:
            pass  # Already removed.
```

- [ ] **Step 2: Verify on device**

In REPL:

```python
import busio
from hardware import pins
from hardware.display import OledDisplay
i2c = busio.I2C(pins.I2C_SCL, pins.I2C_SDA)
disp = OledDisplay(i2c)
disp.show_workscreen(channel=1)
import time; time.sleep(2)
disp.update_values(wheel_a=0x40, wheel_b=0x7F)
time.sleep(2)
disp.update_channel(10)
```

Verify: display shows "Ch  1", wheel values, then updates.

- [ ] **Step 3: Commit**

```bash
git add circuitpython/lib/hardware/display.py
git commit -m "feat: add OledDisplay with workscreen, text rendering, and 180° rotation"
```

---

### Task 7: UartMidi — DIN MIDI In/Out

**Files:**
- Create: `circuitpython/lib/hardware/midi_uart.py`

- [ ] **Step 1: Write `midi_uart.py`**

Create `circuitpython/lib/hardware/midi_uart.py`:

```python
# midi_uart.py — DIN MIDI input and output over UART.
#
# Wraps adafruit_midi over a busio.UART at the standard MIDI baud rate
# of 31250. Connects to a DIN MIDI circuit (optocoupler for input,
# resistor network for output) or an Adafruit MIDI FeatherWing.
#
# Both UartMidi and UsbHostMidi use adafruit_midi message types, so
# MidiMerge can treat them identically.
#
# Usage:
#     from hardware.midi_uart import UartMidi
#     from hardware import pins
#     midi = UartMidi(pins.UART_TX, pins.UART_RX)
#     msg = midi.receive()
#     if msg is not None:
#         print(f"Got: {msg}")
#     midi.send_cc(1, 64, channel=1)

import busio
import adafruit_midi
from adafruit_midi.control_change import ControlChange
from adafruit_midi.pitch_bend import PitchBend
from adafruit_midi.channel_pressure import ChannelPressure

# Standard MIDI baud rate.
_MIDI_BAUD = 31250

class UartMidi:
    """DIN MIDI input and output over UART.

    Provides receive() for reading incoming MIDI messages and send methods
    for outgoing messages. Uses adafruit_midi message types internally.

    Args:
        tx_pin: Board pin for UART TX (MIDI Out).
        rx_pin: Board pin for UART RX (MIDI In).
        channel: Default MIDI channel for sending (0-15, where 0 = channel 1).
            Can be overridden per-send call.
    """

    def __init__(self, tx_pin, rx_pin, channel=0):
        self._uart = busio.UART(tx_pin, rx_pin, baudrate=_MIDI_BAUD, timeout=0.001)
        # adafruit_midi.MIDI wraps a UART-like stream for message parsing.
        self._midi_in = adafruit_midi.MIDI(midi_in=self._uart, in_channel=None)
        self._midi_out = adafruit_midi.MIDI(midi_out=self._uart, out_channel=channel)

    def set_channel(self, channel):
        """Update the default output channel.

        Args:
            channel: MIDI channel (1-16).
        """
        self._midi_out.out_channel = channel - 1

    def receive(self):
        """Read one MIDI message from the DIN input, if available.

        Returns:
            An adafruit_midi message object, or None if no complete message
            is available yet.
        """
        return self._midi_in.receive()

    def send(self, msg):
        """Send a MIDI message object to the DIN output.

        Args:
            msg: An adafruit_midi message (NoteOn, ControlChange, PitchBend, etc.).
        """
        self._midi_out.send(msg)

    def send_cc(self, cc_number, value, channel=None):
        """Send a MIDI Control Change message.

        Args:
            cc_number: CC number (0-127).
            value: CC value (0-127).
            channel: MIDI channel (1-16). Uses default channel if None.
        """
        ch = (channel - 1) if channel is not None else None
        msg = ControlChange(cc_number, value)
        if ch is not None:
            msg.channel = ch
        self._midi_out.send(msg)

    def send_pitch_bend(self, value, channel=None):
        """Send a MIDI Pitch Bend message.

        Args:
            value: Pitch bend value (-8192 to 8191).
            channel: MIDI channel (1-16). Uses default channel if None.
        """
        ch = (channel - 1) if channel is not None else None
        msg = PitchBend(value)
        if ch is not None:
            msg.channel = ch
        self._midi_out.send(msg)

    def send_aftertouch(self, value, channel=None):
        """Send a MIDI Channel Pressure (Aftertouch) message.

        Args:
            value: Pressure value (0-127).
            channel: MIDI channel (1-16). Uses default channel if None.
        """
        ch = (channel - 1) if channel is not None else None
        msg = ChannelPressure(value)
        if ch is not None:
            msg.channel = ch
        self._midi_out.send(msg)
```

- [ ] **Step 2: Verify on device**

Connect DIN MIDI Out to a MIDI monitor (or loop back to a computer via MIDI interface). In REPL:

```python
from hardware.midi_uart import UartMidi
from hardware import pins
midi = UartMidi(pins.UART_TX, pins.UART_RX)
midi.send_cc(1, 64, channel=1)       # Mod wheel to center
midi.send_pitch_bend(0, channel=1)   # Pitch bend center
midi.send_aftertouch(100, channel=1) # Aftertouch
print("Sent 3 messages — check MIDI monitor")
```

Verify messages arrive on the MIDI monitor.

- [ ] **Step 3: Commit**

```bash
git add circuitpython/lib/hardware/midi_uart.py
git commit -m "feat: add UartMidi for DIN MIDI In/Out over UART"
```

---

### Task 8: UsbHostMidi — USB Host Input via MAX3421E

**Files:**
- Create: `circuitpython/lib/hardware/midi_usb_host.py`

- [ ] **Step 1: Write `midi_usb_host.py`**

Create `circuitpython/lib/hardware/midi_usb_host.py`:

```python
# midi_usb_host.py — USB Host MIDI input via MAX3421E breakout.
#
# Reads MIDI messages from a USB MIDI device (e.g., Novation Launchpad Pro 3)
# connected to the MAX3421E USB Host controller over SPI.
#
# This module handles:
# - SPI communication with the MAX3421E chip
# - USB device enumeration and MIDI interface detection
# - Hot-plug: graceful handling of connect/disconnect without crashing
# - Translating USB MIDI packets into adafruit_midi message objects
#   (same types as UartMidi, so MidiMerge can treat both identically)
#
# No device filtering is applied — any USB MIDI class-compliant device
# is accepted.
#
# Usage:
#     import busio
#     from hardware import pins
#     from hardware.midi_usb_host import UsbHostMidi
#     spi = busio.SPI(pins.SPI_CLK, MOSI=pins.SPI_MOSI, MISO=pins.SPI_MISO)
#     usb_midi = UsbHostMidi(spi, pins.USB_HOST_CS)
#     msg = usb_midi.receive()  # Returns adafruit_midi message or None

import digitalio
import max3421e
import usb.core
import adafruit_usb_host_midi
import adafruit_midi

class UsbHostMidi:
    """USB Host MIDI input via MAX3421E.

    Receives MIDI messages from a USB MIDI device connected to the
    MAX3421E breakout. Handles hot-plug gracefully.

    Args:
        spi: A busio.SPI instance for the MAX3421E.
        cs_pin: A board pin for the MAX3421E chip select.
    """

    def __init__(self, spi, cs_pin):
        self._spi = spi
        self._cs_pin = cs_pin
        self._host_chip = None
        self._midi_device = None
        self._midi_in = None
        self._init_host()

    def _init_host(self):
        """Initialize the MAX3421E USB Host controller.

        Called at startup. Sets up the chip select pin and creates
        the MAX3421E host object.
        """
        try:
            cs = digitalio.DigitalInOut(self._cs_pin)
            cs.direction = digitalio.Direction.OUTPUT
            cs.value = True
            self._host_chip = max3421e.MAX3421E(self._spi, cs)
            self._find_midi_device()
        except Exception:
            # MAX3421E not responding or not present — operate without USB input.
            self._host_chip = None
            self._midi_device = None
            self._midi_in = None

    def _find_midi_device(self):
        """Scan connected USB devices for a MIDI class-compliant interface.

        If found, wraps it in adafruit_midi.MIDI for message parsing.
        If not found, sets _midi_in to None (receive() will return None).
        """
        try:
            if self._host_chip is None:
                return
            # Find any connected USB MIDI device via usb.core.
            device = usb.core.find(find_all=False)
            if device is None:
                return
            raw_midi = adafruit_usb_host_midi.MIDI(device)
            self._midi_device = raw_midi
            self._midi_in = adafruit_midi.MIDI(midi_in=raw_midi, in_channel=None)
        except Exception:
            # No MIDI device found — that's fine, we'll try again on next call.
            self._midi_device = None
            self._midi_in = None

    def receive(self):
        """Read one MIDI message from the USB device, if available.

        Returns:
            An adafruit_midi message object, or None if no device is
            connected or no message is available.
        """
        # If no MIDI interface is active, try to find one (hot-plug).
        if self._midi_in is None:
            self._find_midi_device()
            if self._midi_in is None:
                return None

        try:
            return self._midi_in.receive()
        except Exception:
            # Device disconnected or communication error.
            # Reset state so we try to re-enumerate next time.
            self._midi_device = None
            self._midi_in = None
            return None
```

- [ ] **Step 2: Verify on device**

Connect the Launchpad Pro 3 (or any USB MIDI device) to the MAX3421E breakout. In REPL:

```python
import busio
from hardware import pins
from hardware.midi_usb_host import UsbHostMidi
spi = busio.SPI(pins.SPI_CLK, MOSI=pins.SPI_MOSI, MISO=pins.SPI_MISO)
usb = UsbHostMidi(spi, pins.USB_HOST_CS)
print("Waiting for MIDI from USB device... (press keys on Launchpad)")
while True:
    msg = usb.receive()
    if msg is not None:
        print(f"USB MIDI: {msg}")
```

Verify: pressing pads on the Launchpad prints NoteOn/NoteOff messages.

- [ ] **Step 3: Commit**

```bash
git add circuitpython/lib/hardware/midi_usb_host.py
git commit -m "feat: add UsbHostMidi for MAX3421E USB Host MIDI input"
```

---

### Task 9: MidiMerge — Merge Engine

**Files:**
- Create: `circuitpython/lib/midi_merge.py`

- [ ] **Step 1: Write `midi_merge.py`**

Create `circuitpython/lib/midi_merge.py`:

```python
# midi_merge.py — MIDI merge engine.
#
# Collects messages from multiple MIDI inputs (USB Host, DIN In) and
# locally injected events (wheels, buttons), then sends everything
# to the configured outputs (DIN Out).
#
# The merge engine does not filter, remap channels, or modify messages.
# USB Host input is always forwarded. DIN input is only forwarded when
# thru_enabled is True (matching the original Teensy behavior).
#
# Usage:
#     merge = MidiMerge(
#         inputs={"usb": usb_midi, "din": uart_midi},
#         outputs=[uart_midi],
#         thru_enabled=False
#     )
#     # In the main loop:
#     merge.process()
#     merge.inject(some_midi_message)
#     # At end of loop:
#     merge.flush()

class MidiMerge:
    """Merges multiple MIDI inputs and locally injected events to outputs.

    The processing order per loop iteration is:
    1. process() — reads all inputs, queues messages for output
    2. inject() — adds locally generated messages (wheels, buttons)
    3. flush() — sends all queued messages to all outputs

    Attributes:
        had_input: True if any external input was received during the
            last process() call. Used to drive the MIDI-in LED.
        thru_enabled: Whether DIN MIDI input is forwarded to outputs.

    Args:
        inputs: Dict mapping source names to input objects. Each input
            must have a receive() method returning a message or None.
            Expected keys: "usb" for USB Host, "din" for DIN MIDI In.
        outputs: List of output objects. Each must have a send(msg) method.
        thru_enabled: If True, DIN input ("din") is forwarded to outputs.
            USB Host input ("usb") is always forwarded regardless.
    """

    def __init__(self, inputs, outputs, thru_enabled=False):
        self.inputs = inputs
        self.outputs = outputs
        self.thru_enabled = thru_enabled
        self.had_input = False
        self._queue = []  # Messages to send this cycle.

    def process(self):
        """Read all MIDI inputs and queue messages for output.

        USB Host input is always forwarded. DIN input is only forwarded
        when thru_enabled is True.

        Call once at the start of each main loop iteration.
        """
        self._queue = []
        self.had_input = False

        for name, source in self.inputs.items():
            # Read all available messages from this source.
            msg = source.receive()
            while msg is not None:
                self.had_input = True
                # DIN input is conditional on thru_enabled.
                # USB input is always forwarded.
                if name != "din" or self.thru_enabled:
                    self._queue.append(msg)
                msg = source.receive()

    def inject(self, msg):
        """Add a locally generated MIDI message to the output queue.

        Used by the main loop to inject wheel and button events.

        Args:
            msg: An adafruit_midi message object.
        """
        self._queue.append(msg)

    def flush(self):
        """Send all queued messages to all outputs.

        Call once at the end of each main loop iteration, after all
        process() and inject() calls are done.
        """
        for msg in self._queue:
            for output in self.outputs:
                output.send(msg)
        self._queue = []

    @property
    def has_output(self):
        """True if there are messages queued for output this cycle.

        Useful for driving the MIDI-out LED.
        """
        return len(self._queue) > 0
```

- [ ] **Step 2: Verify on device**

Connect Launchpad via USB Host and DIN MIDI Out to a monitor. In REPL:

```python
import busio
from hardware import pins
from hardware.midi_uart import UartMidi
from hardware.midi_usb_host import UsbHostMidi
from midi_merge import MidiMerge
from adafruit_midi.control_change import ControlChange

spi = busio.SPI(pins.SPI_CLK, MOSI=pins.SPI_MOSI, MISO=pins.SPI_MISO)
uart = UartMidi(pins.UART_TX, pins.UART_RX)
usb = UsbHostMidi(spi, pins.USB_HOST_CS)

merge = MidiMerge(
    inputs={"usb": usb, "din": uart},
    outputs=[uart],
    thru_enabled=False
)

# Inject a local CC message and flush
merge.process()
merge.inject(ControlChange(1, 100))
merge.flush()
print("Sent CC1=100 via merge — check MIDI monitor")

# Now press keys on Launchpad and verify they appear on MIDI Out
print("Press Launchpad pads...")
for _ in range(100):
    merge.process()
    if merge.had_input:
        print("Got USB input, forwarding...")
    merge.flush()
    import time; time.sleep(0.05)
```

- [ ] **Step 3: Commit**

```bash
git add circuitpython/lib/midi_merge.py
git commit -m "feat: add MidiMerge engine with USB/DIN input and inject support"
```

---

### Task 10: WheelCalibration — Interactive Calibration Routine

**Files:**
- Create: `circuitpython/lib/calibration.py`

- [ ] **Step 1: Write `calibration.py`**

Create `circuitpython/lib/calibration.py`:

```python
# calibration.py — Interactive wheel calibration routine.
#
# Guides the user through calibrating the pitch bend and mod wheel:
# 1. Display instructions on the OLED
# 2. Wait for button press
# 3. Read current analog values as center/delta reference points
# 4. Save calibration values to ConfigManager
#
# This routine blocks the main loop (MIDI processing stops), matching
# the original Teensy behavior. It is only invoked from the on-device menu.
#
# Usage:
#     from calibration import WheelCalibration
#     cal = WheelCalibration(display, wheel_a, wheel_b, button_b, config)
#     cal.run()

import analogio
from hardware.wheels import _ADC_SHIFT

class WheelCalibration:
    """Interactive calibration for the analog wheels.

    Measures the resting position of each wheel and stores the values
    in the ConfigManager. The pitch bend wheel's center position and
    the mod wheel's zero position are determined.

    Args:
        display: An OledDisplay instance for showing instructions.
        wheel_a: The AnalogWheel for wheel A (pitch bend).
        wheel_b: The AnalogWheel for wheel B (mod wheel).
        button_b: The DebouncedButton used to confirm (Button B).
        config: The ConfigManager instance to save calibration values.
    """

    def __init__(self, display, wheel_a, wheel_b, button_b, config):
        self._display = display
        self._wheel_a = wheel_a
        self._wheel_b = wheel_b
        self._button = button_b
        self._config = config

    def run(self):
        """Run the interactive calibration sequence.

        Blocks until calibration is complete (user presses Button B twice).
        """
        # Step 1: Show instructions.
        self._display.clear()
        self._display.show_text(0, 6, "Calibrate Wheels", inverted=True)
        self._display.show_text(0, 20, "Release Pitch Wh")
        self._display.show_text(0, 30, "and return MODWh")
        self._display.show_text(0, 40, "to zero position")
        self._display.show_text(0, 50, "and press button")

        # Step 2: Wait for Button B press.
        self._wait_for_press()

        # Step 3: Read raw analog values (scaled to 10-bit for compatibility).
        raw_a = self._wheel_a._adc.value >> _ADC_SHIFT
        raw_b = self._wheel_b._adc.value >> _ADC_SHIFT

        # Wheel A (pitch bend): center is the current reading,
        # delta is center - 128 (the offset from ADC zero to pot zero).
        wheel_a_center = raw_a
        wheel_a_delta = raw_a - 128

        # Wheel B (mod wheel): delta is the current reading (zero position),
        # center is delta + 128 (used if wheel B is ever set to pitch bend mode).
        wheel_b_delta = raw_b
        wheel_b_center = raw_b + 128

        # Step 4: Save to config.
        self._config.set("wheel_a.calibration.center", wheel_a_center)
        self._config.set("wheel_a.calibration.delta", wheel_a_delta)
        self._config.set("wheel_b.calibration.center", wheel_b_center)
        self._config.set("wheel_b.calibration.delta", wheel_b_delta)

        # Update the wheel objects with the new calibration values.
        self._wheel_a.calibrate(center=wheel_a_center, delta=wheel_a_delta)
        self._wheel_b.calibrate(center=wheel_b_center, delta=wheel_b_delta)

        # Step 5: Show confirmation with the measured values.
        self._display.clear()
        self._display.show_text(0, 6, "Calibration Done", inverted=True)
        self._display.show_text(0, 24, f"WA ctr: {wheel_a_center:4d}")
        self._display.show_text(0, 36, f"WA dlt: {wheel_a_delta:4d}")
        self._display.show_text(0, 48, f"WB dlt: {wheel_b_delta:4d}")
        self._display.show_text(48, 56, "OK", scale=2)

        # Step 6: Wait for confirmation press, then return.
        self._wait_for_press()

    def _wait_for_press(self):
        """Block until Button B is pressed (fell edge detected)."""
        import time
        # First, wait for button to be released (in case it's still held).
        while True:
            self._button.update()
            if not self._button.pressed:
                break
            time.sleep(0.01)  # Yield CPU to avoid 100% spin.

        # Then wait for a new press.
        while True:
            self._button.update()
            if self._button.fell:
                return
            time.sleep(0.01)
```

- [ ] **Step 2: Verify on device**

This requires the display, wheels, and a button. Best tested as part of Task 11 (menu) or by running directly:

```python
import busio
from hardware import pins
from hardware.display import OledDisplay
from hardware.wheels import AnalogWheel
from hardware.buttons import DebouncedButton
from config import ConfigManager
from calibration import WheelCalibration

i2c = busio.I2C(pins.I2C_SCL, pins.I2C_SDA)
disp = OledDisplay(i2c)
wa = AnalogWheel(pins.WHEEL_A, mode="pitch_bend")
wb = AnalogWheel(pins.WHEEL_B, mode="cc")
btn = DebouncedButton(pins.BUTTON_B)
cfg = ConfigManager("config.json")
cfg.load()

cal = WheelCalibration(disp, wa, wb, btn, cfg)
cal.run()
cfg.save()
print(f"Saved: wheel_a center={cfg.get('wheel_a.calibration.center')}")
```

- [ ] **Step 3: Commit**

```bash
git add circuitpython/lib/calibration.py
git commit -m "feat: add WheelCalibration interactive routine"
```

---

### Task 11: OnDeviceMenu — Configuration Menu

**Files:**
- Create: `circuitpython/lib/menu.py`

- [ ] **Step 1: Write `menu.py`**

Create `circuitpython/lib/menu.py`:

```python
# menu.py — On-device configuration menu.
#
# Provides an interactive menu displayed on the OLED, navigated with
# buttons and the mod wheel. Allows the user to configure:
# - CC assignments for wheels and buttons (CC 0-127, or PWH/ATO special modes)
# - MIDI transmit channel (1-16)
# - MIDI Thru on/off
# - Aftertouch default value (0-127)
# - Deadband width (0-63)
# - Wheel calibration (launches calibration.py)
#
# The menu blocks the main loop — MIDI processing stops while active.
# This matches the original Teensy behavior and is intentional (menu
# interaction is brief and infrequent).
#
# Navigation:
# - Button A: step to next option
# - Button B: confirm/toggle value
# - Wheel B: scroll value
# - Select "X" (top right) to exit
#
# Triggered by double-clicking Button A in the main loop.
#
# Usage:
#     menu = OnDeviceMenu(display, config, wheel_b, button_a, button_b, calibration)
#     menu.enter()  # Blocks until user exits menu

from calibration import WheelCalibration

# Menu item definitions. Each tuple: (display_label, config_dotpath, item_type, value_range)
# item_type: "cc_or_special" (0-127 + PWH/ATO), "channel" (1-16),
#            "bool" (ON/OFF), "value" (numeric), "action" (triggers a function)
_MENU_ITEMS = [
    ("Wh A", "wheel_a", "wheel_mode", None),
    ("Wh B", "wheel_b", "wheel_mode", None),
    ("BtnA", "button_a", "button_mode", None),
    ("BtnB", "button_b", "button_mode", None),
    ("FtSw", "footswitch", "button_mode", None),
    ("TxCh", "midi.tx_channel", "channel", (1, 16)),
    ("Thru", "midi.thru_enabled", "bool", None),
    ("ATO ", "button_b.aftertouch_value", "value", (0, 127)),
    ("DB  ", "deadband", "value", (0, 63)),
    ("CAL ", None, "action", None),
]

class OnDeviceMenu:
    """On-device configuration menu displayed on the OLED.

    Args:
        display: An OledDisplay instance.
        config: A ConfigManager instance.
        wheel_b: The AnalogWheel for wheel B (used to scroll values).
        button_a: DebouncedButton for stepping through options.
        button_b: DebouncedButton for confirming/toggling.
        wheel_a: AnalogWheel for wheel A (needed by calibration).
    """

    def __init__(self, display, config, wheel_a, wheel_b, button_a, button_b):
        self._display = display
        self._config = config
        self._wheel_a = wheel_a
        self._wheel_b = wheel_b
        self._btn_a = button_a
        self._btn_b = button_b
        self._selected = 0  # Currently highlighted menu item index.

    def enter(self):
        """Enter the menu. Blocks until the user exits.

        On exit, saves the configuration to disk.
        """
        self._draw_menu()
        wheel_moved = False
        wheel_old = self._wheel_b.read()

        import time
        while True:
            self._btn_a.update()
            self._btn_b.update()

            # Check if wheel has moved significantly.
            wheel_val = self._wheel_b.read()
            if not wheel_moved:
                diff = abs(wheel_val - wheel_old)
                wheel_moved = diff > 5

            # Handle Button A: step to next item.
            if self._btn_a.fell:
                self._selected = (self._selected + 1) % (len(_MENU_ITEMS) + 1)
                wheel_moved = False
                wheel_old = wheel_val
                self._draw_menu()

            # Handle Button B: confirm/toggle current item.
            if self._btn_b.fell:
                # Exit item (index == len means the "X" close button).
                if self._selected == len(_MENU_ITEMS):
                    break

                item = _MENU_ITEMS[self._selected]
                self._handle_confirm(item)
                self._draw_menu()

            # Handle wheel scrolling for current item.
            if wheel_moved and self._selected < len(_MENU_ITEMS):
                item = _MENU_ITEMS[self._selected]
                self._handle_wheel(item, wheel_val)
                self._draw_menu()

            time.sleep(0.01)  # Yield CPU to avoid 100% spin.

        # Save all changes on menu exit.
        self._config.save()

    def _draw_menu(self):
        """Redraw the entire menu screen."""
        self._display.clear()

        # Header.
        self._display.show_text(0, 6, "LCC2 Config", inverted=True)

        # Menu items in two columns (5 items each) to fit all 10 items.
        # Column 1: items 0-4 on the left, Column 2: items 5-9 on the right.
        # Matches the original Teensy two-column layout.
        for i, item in enumerate(_MENU_ITEMS):
            label_text, dotpath, item_type, _ = item
            inverted = (i == self._selected)

            col = i // 5           # 0 = left column, 1 = right column
            row = i % 5            # 0-4 within each column
            x = col * 64           # Left column at x=0, right at x=64
            y = 18 + row * 10      # 5 rows starting at y=18

            val_text = self._format_value(item)
            line = f"{label_text}:{val_text}"
            self._display.show_text(x, y, line, inverted=inverted)

        # "X" close button at top right.
        self._display.show_text(116, 6, "X",
                                inverted=(self._selected == len(_MENU_ITEMS)))

    def _format_value(self, item):
        """Format a menu item's current value for display."""
        _, dotpath, item_type, _ = item

        if item_type == "action":
            return "GO"

        if item_type == "wheel_mode":
            mode = self._config.get(f"{dotpath}.mode")
            if mode == "pitch_bend":
                return "PWH"
            cc = self._config.get(f"{dotpath}.cc_number")
            return f"{cc:3d}" if cc is not None else "---"

        if item_type == "button_mode":
            mode = self._config.get(f"{dotpath}.mode")
            if mode == "aftertouch":
                return "ATO"
            cc = self._config.get(f"{dotpath}.cc_number")
            return f"{cc:3d}" if cc is not None else "---"

        if item_type == "channel":
            return f"{self._config.get(dotpath):3d}"

        if item_type == "bool":
            return " ON" if self._config.get(dotpath) else "OFF"

        if item_type == "value":
            return f"{self._config.get(dotpath):3d}"

        return "???"

    def _handle_confirm(self, item):
        """Handle Button B press on the currently selected item."""
        _, dotpath, item_type, val_range = item

        if item_type == "action":
            # Launch calibration.
            cal = WheelCalibration(self._display, self._wheel_a, self._wheel_b,
                                   self._btn_b, self._config)
            cal.run()
            return

        if item_type == "wheel_mode":
            # Toggle: cc → pitch_bend → cc, cycling CC number on each press.
            mode = self._config.get(f"{dotpath}.mode")
            if mode == "pitch_bend":
                self._config.set(f"{dotpath}.mode", "cc")
                if self._config.get(f"{dotpath}.cc_number") is None:
                    self._config.set(f"{dotpath}.cc_number", 1)
            else:
                cc = self._config.get(f"{dotpath}.cc_number")
                if cc is not None and cc < 127:
                    self._config.set(f"{dotpath}.cc_number", cc + 1)
                else:
                    self._config.set(f"{dotpath}.mode", "pitch_bend")
                    self._config.set(f"{dotpath}.cc_number", None)
            return

        if item_type == "button_mode":
            # Toggle: cc → aftertouch → cc, cycling CC number on each press.
            mode = self._config.get(f"{dotpath}.mode")
            if mode == "aftertouch":
                self._config.set(f"{dotpath}.mode", "cc")
                if self._config.get(f"{dotpath}.cc_number") is None:
                    self._config.set(f"{dotpath}.cc_number", 64)
            else:
                cc = self._config.get(f"{dotpath}.cc_number")
                if cc is not None and cc < 127:
                    self._config.set(f"{dotpath}.cc_number", cc + 1)
                else:
                    self._config.set(f"{dotpath}.mode", "aftertouch")
            return

        if item_type == "channel":
            val = self._config.get(dotpath)
            val = val + 1 if val < 16 else 1
            self._config.set(dotpath, val)
            return

        if item_type == "bool":
            self._config.set(dotpath, not self._config.get(dotpath))
            return

        if item_type == "value":
            lo, hi = val_range
            val = self._config.get(dotpath)
            val = val + 1 if val < hi else lo
            self._config.set(dotpath, val)
            return

    def _handle_wheel(self, item, wheel_val):
        """Handle wheel B scrolling for the currently selected item."""
        _, dotpath, item_type, val_range = item

        if item_type == "action":
            return  # No wheel control for calibration.

        if item_type == "wheel_mode":
            # Map wheel 0-127 to CC 0-127 or pitch_bend at max.
            if wheel_val >= 127:
                self._config.set(f"{dotpath}.mode", "pitch_bend")
                self._config.set(f"{dotpath}.cc_number", None)
            else:
                self._config.set(f"{dotpath}.mode", "cc")
                self._config.set(f"{dotpath}.cc_number", wheel_val)
            return

        if item_type == "button_mode":
            if wheel_val >= 127:
                self._config.set(f"{dotpath}.mode", "aftertouch")
            else:
                self._config.set(f"{dotpath}.mode", "cc")
                self._config.set(f"{dotpath}.cc_number", wheel_val)
            return

        if item_type == "channel":
            # Map wheel 0-127 to 1-16.
            self._config.set(dotpath, (wheel_val * 15 // 127) + 1)
            return

        if item_type == "bool":
            self._config.set(dotpath, wheel_val > 63)
            return

        if item_type == "value":
            lo, hi = val_range
            # Map wheel 0-127 to lo..hi range.
            mapped = lo + (wheel_val * (hi - lo) // 127)
            self._config.set(dotpath, mapped)
            return
```

- [ ] **Step 2: Verify on device**

Full menu test with all hardware connected:

```python
import busio
from hardware import pins
from hardware.display import OledDisplay
from hardware.wheels import AnalogWheel
from hardware.buttons import DebouncedButton
from config import ConfigManager
from menu import OnDeviceMenu

i2c = busio.I2C(pins.I2C_SCL, pins.I2C_SDA)
disp = OledDisplay(i2c)
wa = AnalogWheel(pins.WHEEL_A, mode="pitch_bend")
wb = AnalogWheel(pins.WHEEL_B, mode="cc")
btn_a = DebouncedButton(pins.BUTTON_A)
btn_b = DebouncedButton(pins.BUTTON_B)
cfg = ConfigManager("config.json")
cfg.load()

menu = OnDeviceMenu(disp, cfg, wa, wb, btn_a, btn_b)
print("Entering menu... Button A=next, Button B=set, Wheel B=scroll")
menu.enter()
print(f"TX Channel after menu: {cfg.get('midi.tx_channel')}")
```

Navigate through all options, change some values, exit. Verify `config.json` was updated.

- [ ] **Step 3: Commit**

```bash
git add circuitpython/lib/menu.py
git commit -m "feat: add OnDeviceMenu with all configuration options"
```

---

### Task 12: code.py — Main Entry Point

**Files:**
- Create: `circuitpython/code.py`

- [ ] **Step 1: Write `code.py`**

Create `circuitpython/code.py`:

```python
# code.py — Main entry point for the MIDI Companion Controller 2.
#
# This file contains ONLY wiring (hardware initialization) and the main
# loop. All business logic lives in the library modules under lib/.
#
# The main loop runs synchronously:
# 1. Update button states
# 2. Check for double-click → enter configuration menu
# 3. Process MIDI inputs (USB Host + DIN In) via MidiMerge
# 4. Read wheels, inject changed values into the merge
# 5. Read buttons, inject CC/Aftertouch events into the merge
# 6. Flush merged messages to DIN MIDI Out
# 7. Update the OLED display
# 8. Blink LEDs for activity indication

import busio

from hardware import pins
from hardware.leds import StatusLED
from hardware.buttons import DebouncedButton
from hardware.wheels import AnalogWheel
from hardware.display import OledDisplay
from hardware.midi_uart import UartMidi
from hardware.midi_usb_host import UsbHostMidi
from midi_merge import MidiMerge
from config import ConfigManager
from menu import OnDeviceMenu
from adafruit_midi.control_change import ControlChange
from adafruit_midi.pitch_bend import PitchBend
from adafruit_midi.channel_pressure import ChannelPressure

# ──────────────────────────────────────────────
# 1. CONFIGURATION
# ──────────────────────────────────────────────
config = ConfigManager("config.json")
config.load()

# ──────────────────────────────────────────────
# 2. HARDWARE INITIALIZATION
# ──────────────────────────────────────────────

# Communication buses.
i2c = busio.I2C(pins.I2C_SCL, pins.I2C_SDA)
spi = busio.SPI(pins.SPI_CLK, MOSI=pins.SPI_MOSI, MISO=pins.SPI_MISO)

# Display.
display = OledDisplay(i2c)

# LEDs.
led_in = StatusLED(pins.LED1)
led_out = StatusLED(pins.LED2)

# Buttons.
button_a = DebouncedButton(pins.BUTTON_A, double_click_ms=250)
button_b = DebouncedButton(pins.BUTTON_B, double_click_ms=0)  # No double-click needed.
footswitch = DebouncedButton(pins.FOOTSWITCH, double_click_ms=0)

# Wheels — mode and calibration loaded from config.
deadband = config.get("deadband")

wheel_a = AnalogWheel(pins.WHEEL_A,
                      mode=config.get("wheel_a.mode"),
                      deadband=deadband)
wheel_a.calibrate(center=config.get("wheel_a.calibration.center"),
                  delta=config.get("wheel_a.calibration.delta"))

wheel_b = AnalogWheel(pins.WHEEL_B,
                      mode=config.get("wheel_b.mode"),
                      deadband=deadband)
wheel_b.calibrate(center=config.get("wheel_b.calibration.center"),
                  delta=config.get("wheel_b.calibration.delta"))

# MIDI interfaces.
uart_midi = UartMidi(pins.UART_TX, pins.UART_RX,
                     channel=config.get("midi.tx_channel") - 1)
usb_midi = UsbHostMidi(spi, pins.USB_HOST_CS)

# MIDI merge engine.
merge = MidiMerge(
    inputs={"usb": usb_midi, "din": uart_midi},
    outputs=[uart_midi],
    thru_enabled=config.get("midi.thru_enabled")
)

# On-device menu.
menu = OnDeviceMenu(display, config, wheel_a, wheel_b, button_a, button_b)

# ──────────────────────────────────────────────
# 3. SHOW STARTUP SCREEN
# ──────────────────────────────────────────────
display.show_workscreen(channel=config.get("midi.tx_channel"))

# ──────────────────────────────────────────────
# 4. MAIN LOOP
# ──────────────────────────────────────────────
while True:

    # --- Update button states ---
    button_a.update()
    button_b.update()
    footswitch.update()

    # --- Double-click Button A → enter menu ---
    if button_a.double_click:
        menu.enter()
        # After menu exit, reload settings that may have changed.
        tx_ch = config.get("midi.tx_channel")
        merge.thru_enabled = config.get("midi.thru_enabled")
        wheel_a.mode = config.get("wheel_a.mode")
        wheel_a.deadband = config.get("deadband")
        wheel_b.mode = config.get("wheel_b.mode")
        wheel_b.deadband = config.get("deadband")
        uart_midi.set_channel(tx_ch)
        display.show_workscreen(channel=tx_ch)
        continue

    # --- Process MIDI inputs (USB Host + DIN) ---
    merge.process()
    if merge.had_input:
        led_in.on()

    # --- Read wheels and inject changes ---
    tx_ch = config.get("midi.tx_channel")
    output_generated = False

    # Wheel A.
    wheel_a.read()
    if wheel_a.changed:
        if config.get("wheel_a.mode") == "pitch_bend":
            msg = PitchBend(wheel_a.value)
            msg.channel = tx_ch - 1
            merge.inject(msg)
        else:
            cc_num = config.get("wheel_a.cc_number")
            msg = ControlChange(cc_num, wheel_a.value)
            msg.channel = tx_ch - 1
            merge.inject(msg)
        output_generated = True

    # Wheel B.
    wheel_b.read()
    if wheel_b.changed:
        if config.get("wheel_b.mode") == "pitch_bend":
            msg = PitchBend(wheel_b.value)
            msg.channel = tx_ch - 1
            merge.inject(msg)
        else:
            cc_num = config.get("wheel_b.cc_number")
            msg = ControlChange(cc_num, wheel_b.value)
            msg.channel = tx_ch - 1
            merge.inject(msg)
        output_generated = True

    # --- Read buttons and inject events ---
    ato_value = config.get("button_b.aftertouch_value")

    # Button A.
    if button_a.fell or button_a.rose:
        if config.get("button_a.mode") == "aftertouch":
            val = ato_value if button_a.fell else 0
            msg = ChannelPressure(val)
        else:
            cc_num = config.get("button_a.cc_number")
            val = 127 if button_a.fell else 0
            msg = ControlChange(cc_num, val)
        msg.channel = tx_ch - 1
        merge.inject(msg)
        output_generated = True

    # Button B.
    if button_b.fell or button_b.rose:
        if config.get("button_b.mode") == "aftertouch":
            val = ato_value if button_b.fell else 0
            msg = ChannelPressure(val)
        else:
            cc_num = config.get("button_b.cc_number")
            val = 127 if button_b.fell else 0
            msg = ControlChange(cc_num, val)
        msg.channel = tx_ch - 1
        merge.inject(msg)
        output_generated = True

    # Footswitch.
    if footswitch.fell or footswitch.rose:
        if config.get("footswitch.mode") == "aftertouch":
            val = ato_value if footswitch.fell else 0
            msg = ChannelPressure(val)
        else:
            cc_num = config.get("footswitch.cc_number")
            val = 127 if footswitch.fell else 0
            msg = ControlChange(cc_num, val)
        msg.channel = tx_ch - 1
        merge.inject(msg)
        output_generated = True

    # --- Flush all queued messages to DIN MIDI Out ---
    if output_generated:
        led_out.on()
    merge.flush()

    # --- Update display (only on value changes) ---
    if wheel_a.changed or wheel_b.changed:
        display.update_values(
            wheel_a=wheel_a.value if wheel_a.changed else None,
            wheel_b=wheel_b.value if wheel_b.changed else None
        )

    # --- LEDs off at end of cycle ---
    led_in.off()
    led_out.off()
```

- [ ] **Step 2: Verify on device — full integration test**

Copy the entire `circuitpython/` directory to the CIRCUITPY drive (including all `lib/` modules and `config.json`). Also install required Adafruit libraries from the CircuitPython Bundle into `lib/`:
- `adafruit_midi/`
- `adafruit_usb_host_midi.mpy`
- `adafruit_max3421e.mpy`
- `adafruit_debouncer.mpy`
- `adafruit_displayio_ssd1306.mpy`
- `adafruit_display_text/`
- `adafruit_ticks.mpy` (dependency of adafruit_debouncer)

The device should auto-run `code.py` on boot. Verify:
1. OLED shows workscreen with "Ch  1"
2. Moving wheels updates hex values on display
3. DIN MIDI Out sends pitch bend / mod wheel CC
4. Pressing buttons sends CC / aftertouch via DIN MIDI Out
5. Connecting Launchpad via USB Host → notes forwarded to DIN Out
6. Double-click Button A → menu appears
7. Change TX channel in menu, exit → workscreen shows new channel
8. LED1 blinks on MIDI input, LED2 blinks on local MIDI output

- [ ] **Step 3: Commit**

```bash
git add circuitpython/code.py
git commit -m "feat: add code.py main loop — complete CircuitPython port"
```

---

### Task 13: Final cleanup and documentation

**Files:**
- Modify: `CLAUDE.md` (add CircuitPython section)

- [ ] **Step 1: Update CLAUDE.md**

Add a CircuitPython section to `CLAUDE.md` documenting:
- How to deploy to the Pico 2 (copy files to CIRCUITPY)
- Required Adafruit libraries
- Dev-mode boot (hold Button A during boot for USB filesystem access)
- Config file location and format

- [ ] **Step 2: Commit**

```bash
git add CLAUDE.md
git commit -m "docs: add CircuitPython deployment instructions to CLAUDE.md"
```

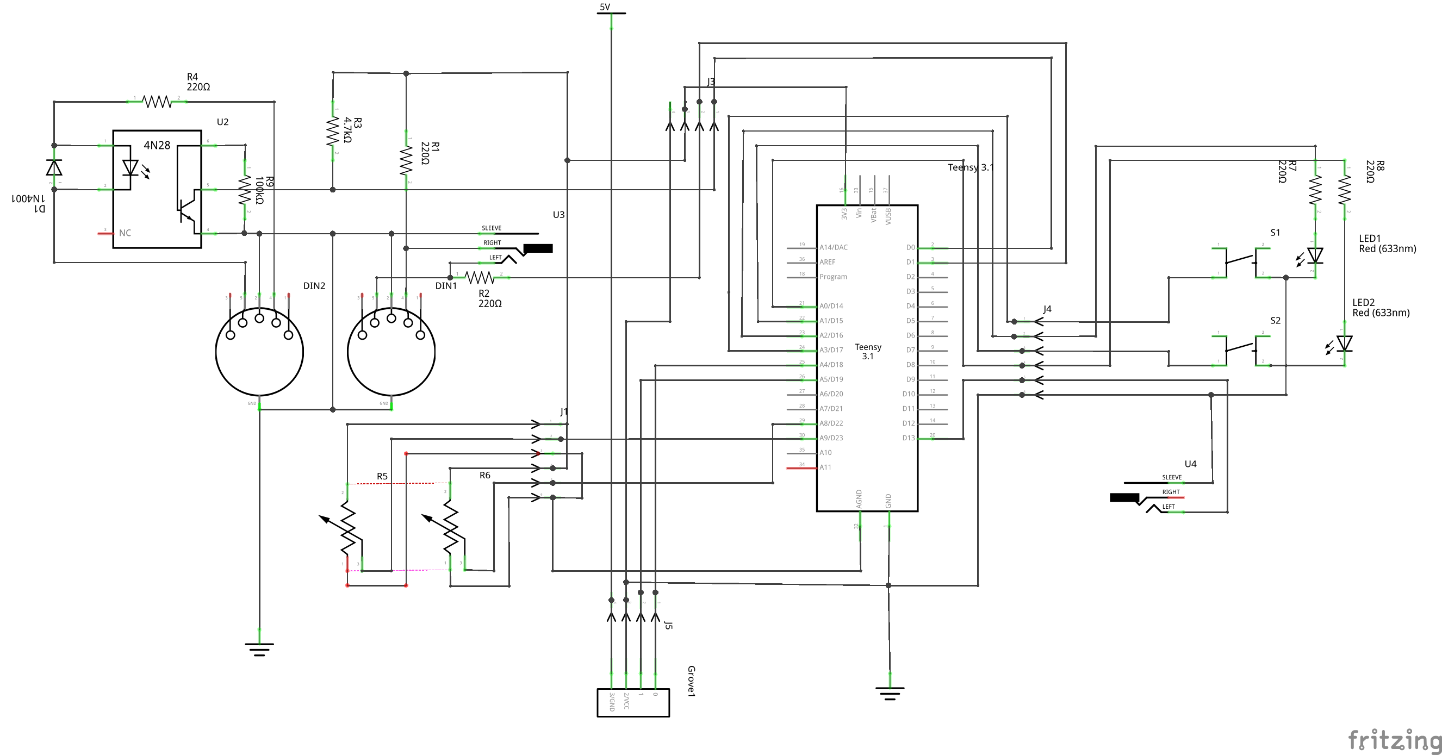
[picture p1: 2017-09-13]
midicompanion2-0_Schematic.png

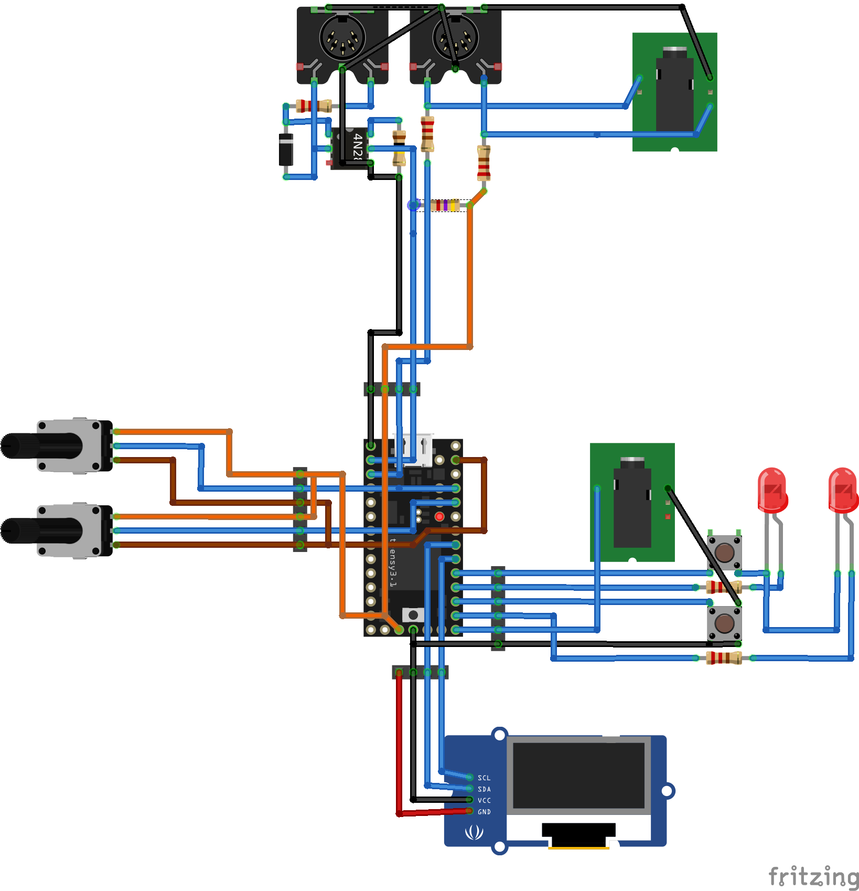
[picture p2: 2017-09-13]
midicompanion2-0_breadboard-plan.png

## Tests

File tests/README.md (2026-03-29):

# Hardware Integration Tests

Host-side tests that communicate with the Pico 2 over USB MIDI and USB serial.

## Prerequisites

- Pico 2 connected via USB, running CircuitPython with the controller firmware
- USB MIDI enabled (default — `boot.py` does not disable it)
- USB CDC serial console enabled (default)
- Python 3.9+ on the host machine

## Setup

```bash
pip install -r tests/requirements.txt
```

## Running Tests

**Automated tests** (no physical interaction needed):
```bash
pytest tests/ -v --ignore=tests/test_wheels_buttons.py
```

**Manual tests** (requires pressing buttons / moving wheels):
```bash
pytest tests/test_wheels_buttons.py -v -s -m manual
```

**All tests:**
```bash
pytest tests/ -v -s
```

## Environment Variables

| Variable | Default | Description |
|---|---|---|
| `MIDI_DEVICE_NAME` | `CircuitPython Audio` | Substring to match in MIDI device names |
| `SERIAL_PORT` | Auto-detect | Serial port for REPL (e.g., `/dev/tty.usbmodem1234`) |

## Test Categories

| File | Tests | Requires |
|---|---|---|
| `test_midi_device.py` | USB MIDI enumeration, port open, thru | Device connected |
| `test_config.py` | Config load/save/validation via REPL | Device in dev mode (writable FS) |
| `test_error_recovery.py` | Corrupt config, MIDI flood | Device in dev mode |
| `test_wheels_buttons.py` | Physical input verification | Human interaction |

## Notes

- Config tests require the device to be in **dev mode** (hold Button A during boot) so the filesystem is writable from both the REPL and USB.
- The REPL tests interrupt the running `code.py` with Ctrl-C. After running tests, reset the device to resume normal operation.

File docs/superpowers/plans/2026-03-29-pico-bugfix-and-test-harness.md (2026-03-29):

# Pico 2 Bug Fix and Host-Side Test Harness — Implementation Plan

**Goal:** Fix all 22 bugs (P1-P22) and address 6 design concerns (D1-D6) in the CircuitPython/Pico 2 MIDI companion controller, then add a host-side pytest test harness (`tests/`) for integration testing over USB MIDI and serial.

**Bug list:** `BUGLIST_PICO.md`
**Hardware reference:** `HARDWARE_PICO.md`

---

## File Map

| File | Changes | Bugs Addressed |
|---|---|---|
| `circuitpython/boot.py` | Fix dev mode pin | P1 |
| `circuitpython/code.py` | Add "off"/"note" modes, guard None CC, fix LED, version, cache config, watchdog, first-boot save | P2, P6, P9, P14, P22, D2, D4, D5, D6 |
| `circuitpython/lib/hardware/midi_usb_host.py` | Narrow exception types, add scan cooldown | P3, P8 |
| `circuitpython/lib/config.py` | Validate on set(), reject unknown keys, return save status, distinguish load errors | P4, P13, P20, D6 |
| `circuitpython/lib/menu.py` | Clamp wheel_b, reset cursor, save feedback | P7, P12, P15 |
| `circuitpython/lib/hardware/display.py` | Fix pitch bend display format | P5 |
| `circuitpython/lib/midi_merge.py` | Bound queue size | P10 |
| `circuitpython/lib/calibration.py` | Add timeout | P11 |
| `circuitpython/lib/hardware/wheels.py` | Fix pitch bend range, document ADC, validate deadband | P16, P18, P19 |
| `circuitpython/lib/hardware/leds.py` | Minimum on-duration | D4 |
| `tests/` | Host-side pytest harness | P21 |

---

## Phase 1: Critical and High-Severity Bugs (P1, P3, P4, P2)

### Task 1.1: Fix dev mode pin in boot.py [P1]
- [ ] Line 37: `board.GP17` → `board.GP0`
- [ ] Line 20: update comment `GP17` → `GP0`

### Task 1.2: Narrow exception handling in midi_usb_host.py [P3]
- [ ] Lines 61, 82, 107, 125: `except Exception:` → `except (OSError, RuntimeError, ValueError):`

### Task 1.3: Add validation to config.set() [P4]
- [ ] Add `_validate_key(dotpath)` method that clamps a single key
- [ ] Call it at the end of `set()`

### Task 1.4: Add "off" and "note" modes in code.py [P2, P9]
- [ ] Wheels: guard with `if mode != "off"`, guard `cc_num is not None`
- [ ] Buttons: add "off" skip, add "note" mode (NoteOn/NoteOff), guard `cc_num is not None`
- [ ] Add `NoteOn`/`NoteOff` imports

**Review checkpoint:** Device boots, dev mode works, all modes send correct MIDI.

---

## Phase 2: Medium-Severity Bugs (P5, P6, P7, P8)

### Task 2.1: Fix pitch bend display [P5]
- [ ] Add mode params to `update_values()` — decimal for pitch_bend, hex for CC
- [ ] Update call site in code.py
- [ ] Widen label initial text for pitch bend values

### Task 2.2: Fix output LED for thru messages [P6]
- [ ] Check `merge.has_output` before flush, light LED for any queued output

### Task 2.3: Fix menu with pitch_bend wheel_b [P7]
- [ ] Temporarily force wheel_b to CC mode during menu, restore on exit

### Task 2.4: Add USB scan cooldown [P8]
- [ ] Add `_SCAN_COOLDOWN_NS = 500_000_000` and `_last_scan_time` in midi_usb_host.py
- [ ] Guard `_find_midi_device()` call with cooldown check

**Review checkpoint:** Display correct, LED for thru, menu safe, no excessive USB scanning.

---

## Phase 3: Medium Weaknesses (P10-P15)

### Task 3.1: Bound MIDI queue [P10]
- [ ] `_MAX_QUEUE = 64`, break/return when exceeded

### Task 3.2: Calibration timeout [P11]
- [ ] 30s timeout in `_wait_for_press()`, return gracefully

### Task 3.3: Save failure feedback [P12]
- [ ] `save()` returns bool, menu shows "SAVE FAILED" on error

### Task 3.4: Distinguish missing vs. corrupt config [P13]
- [ ] `load()` returns status string, code.py shows warning for "corrupt"

### Task 3.5: Document aftertouch key [P14]
- [ ] Add clarifying comments in config.py and code.py

### Task 3.6: Reset menu cursor [P15]
- [ ] `self._selected = 0` at start of `enter()`

**Review checkpoint:** Queue bounded, calibration has timeout, save feedback works.

---

## Phase 4: Low-Severity Issues and Design Concerns

### Task 4.1: Document ADC shift [P16]
### Task 4.2: Strengthen echo prevention naming [P17]
### Task 4.3: Validate deadband [P18]
### Task 4.4: Fix pitch bend full range [P19]
- [ ] Replace `v * 64` with `v * 8191 // 127` (positive) / `v * 8192 // 128` (negative)

### Task 4.5: Reject unknown config keys [P20]
### Task 4.6: Add firmware version [P22]
### Task 4.7: Design concerns [D1-D6]
- [ ] D2: Add watchdog (5s timeout, feed in main loop + menu + calibration)
- [ ] D4: LED minimum on-time (50ms)
- [ ] D5: Cache config values as locals, reload after menu
- [ ] D6: Save defaults on first boot

**Review checkpoint:** All P-items and D-items addressed.

---

## Phase 5: Host-Side Test Harness

### Task 5.1: Project setup
- [ ] `tests/requirements.txt` (pytest, mido, python-rtmidi, pyserial)
- [ ] `tests/README.md`
- [ ] `.vscode/settings.json` pytest config
- [ ] `pyproject.toml` with pytest markers

### Task 5.2: Test fixtures (`tests/conftest.py`)
- [ ] `midi_out` / `midi_in` fixtures via mido
- [ ] `serial_repl` / `repl` fixtures via pyserial

### Task 5.3: USB MIDI device tests (`tests/test_midi_device.py`)
- [ ] Device enumeration, port open, MIDI thru

### Task 5.4: Wheel/button tests (`tests/test_wheels_buttons.py`)
- [ ] Manual-marked tests for physical input verification

### Task 5.5: Config tests (`tests/test_config.py`)
- [ ] Load, set, persist, validation clamping

### Task 5.6: Error recovery tests (`tests/test_error_recovery.py`)
- [ ] Corrupt config recovery, MIDI flood survival

**Review checkpoint:** All tests pass with device connected.

---

## Phase 6: Verification

- [ ] Run automated tests: `pytest tests/ -v`
- [ ] Run manual tests: `pytest tests/ -v -m manual`
- [ ] Update BUGLIST_PICO.md marking bugs as fixed
- [ ] Smoke test: boot, dev mode, all modes, menu, calibration timeout, thru LED, watchdog

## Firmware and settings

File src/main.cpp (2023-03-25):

// ------------------------------------------------------------------------
// Simple MIDI Controller, based on Teensy 3.2
// Derived from V1.0 with SparkFun DangerShield and Arduino
// CC-BY untergeek.de                              V2.0, 9-Aug-2017
//
// Crude and simple code which turns the DangerShield into a MIDI controller
// with pitch bend and CC wheels (Modwheel per default), and three 
// performance controller keys. MIDI input is read for the MIDI channel used
// and echoed to MIDI Out. Generated MIDI data (Pitch Bend, ATO, and CCs) is merged
// with echoed MIDI. 
//
// Todo: 
// -- String handler
// --- Overload printf function??
// -- UTF-8 conversion? 
// --- (Chipset is CP437 at the moment, maybe CP1252 later)
// Nice-to-have: 
// - Interrupt-based clocking of input scanning and MIDI output for more 
// ----------------------------------------------------------


// MIDI library includes - serial MIDI, USB MIDI as a class-compliant device
// To compile for a USB MIDI enabled device like the Teensy, you will have to
// - (in the Arduino/Teensyduino IDE) select Tools->USB Type->MIDI, OR
// - (in the PlatformIO IDE) add a variable to the platformio.ini file: build_flags = -UUSB_SERIAL -DUSB_MIDI

#define HAS_USBMIDI TRUE

// Needs my OLED_I2C_128x64_Monochrome library to link:
// https://github.com/untergeekDE/OLED_I2C_128x64_Monochrome_Library

#include <Arduino.h>

#include <MIDI.h>
#include <SPI.h>
#include <Wire.h>

#include <avr/pgmspace.h>

#include <Bounce2.h>
#include <EEPROM.h>

#include <OLED_I2C_128x64_Monochrome.h>

#define OLED_RESET 4

const byte VERSION[] PROGMEM = "FW V0.6";

// V0.6: 
// - calibrate() routine extended to adjust for deadband and center
// - Fixed code to compile on PlatformIO IDE
// - Got rid of midiUSB special function; conditional compile
// V0.5:
// - Changed the display handling
// V0.4: 
// - Adjustable deadband
// - Bounce2 debounce library
// - Detect double click to call menu 
// V0.3:
// - Menu routine to configure EEPROM parameters
// - Negative characters (white background)
// V0.2: 
// - Generalized Wheel and Button handling routines (no hard-coded CC)
// - MIDI Thru parameter
// - LEDs fixed: LED1 signals MIDI input, LED2 signals MIDI output (w/o thru)




// Constructor display


// MIDI constructor micros: 
// Set serial MIDI I/O as "midiA"
// Use midiUSB commands for USB MIDI 

    MIDI_CREATE_INSTANCE(HardwareSerial, Serial1, midiA);
    #ifdef HAS_USBMIDI 
      MIDI_CREATE_INSTANCE(HardwareSerial, SerialUSB, midiB);
    #endif

// DangerShield CapSense proximity sensor, read with the "CapSense" library
// Definitions enabling the CapSense function which we do not use yet
// #include <CapSense.h>

// CONSTANTS
// Wheel definitions

#define WHEEL_A  22 //Left Wheel, Pitch Bend 
#define WHEEL_B  23 //Right Wheel

#define BUTTON_A  17 //Left button
#define BUTTON_B  15 //Right button
#define BUTTON_C  13 //External button

#define LED1  16 // Top LED signals MIDI input
#define LED2  14 // Bottom LED signals generated MIDI output


// MIDI CC definitions
#define CCSLIDER_B 1 // Mod Wheel
#define CCSLIDER_C 2 // Breath

#define CCBUTTON_B 64 // Sustain
#define CCBUTTON_C 66 // Sostenuto

#define DEFAULT_MIDI_CH 1

// "Deadband" zones for Pitch Bend: Only 7/8 of each half of the fader
// produce changes; values around the middle are nulled

// Global variables
byte MidiRxCh = 0;
byte MidiTxCh = DEFAULT_MIDI_CH;
int wheel_a_delta, wheel_a_center; 
int wheel_b_delta, wheel_b_center;
byte deadband;
int value;
int value_wheel_a = 0, value_wheel_b = 0;

long doubleclick = 0; // millis tick for double-click detection

#define DC 250    // 250ms, two clicks in this time range count as double click

boolean RefreshFlag = false;

/********************************************** STRING CONSTANTS ***************************************************/
// The OLED library I extended has no proper print(); and println(); functions like its Adafruit_gfx counterpart.
// Strings are defined as PROGMEM constant and passed by a named referrer. Simple but effective. 

// Startup message
const byte t1[] PROGMEM = "LpCompanionCtrl2";
const byte t2[] PROGMEM = "----------------";
const byte t3[] PROGMEM = "Ch ";
const byte t4[] PROGMEM = "www.untergeek.de";

// Menu texts
const byte m0[] PROGMEM = "LCC2 ";
const byte m1[] PROGMEM = "------cc------xx";
const byte m2[] PROGMEM = "Wh A:    TxCh   ";
const byte m3[] PROGMEM = "Wh B:    Thru   ";
const byte m4[] PROGMEM = "BtnA:    Ato    ";
const byte m5[] PROGMEM = "BtnB:    DB     ";
const byte m6[] PROGMEM = "FtSw:    CAL    ";

const byte m7[] PROGMEM = "PWH"; 
const byte m8[] PROGMEM = "ATO";
const byte m9[] PROGMEM = " ON";
const byte ma[] PROGMEM = "OFF";


// Calibration texts
const byte c0[] PROGMEM = "Calibrate Wheels";
const byte c1[] PROGMEM = "Release Pitch Wh";
const byte c2[] PROGMEM = "and return MODWh";
const byte c3[] PROGMEM = "to zero position";
const byte c4[] PROGMEM = "and press button";
const byte c5[] PROGMEM = "OK";


   
/********************************************** PRINT ROUTINES ***************************************************/


// writeText routine nicked and repurposed from Adafruit and Deloarts code

void print(char *str)
{
  char * s = (char *) str; 
  print(s); 
}

void print(byte *str)
{
  // SET PROGMEM BUFFER
  unsigned char c;
  // PRINT CHAR FROM PROGMEM
  
  if (!str)
  {
    return;
  }
    while ((c = *str++))
    {
 
        oled.printChar(c);
    }
}

void print(const byte str[])
{
  // SET PROGMEM BUFFER
  unsigned char c;
  // PRINT CHAR FROM PROGMEM
  if (!str)
  {
    return;
  }
    while ((c = pgm_read_byte(str++)))
    {
 
        oled.printChar(c);
    }
}

// This is called/shown in normal operation: MIDI channel, values read from the wheels, buttons/foot switch
// Might add small MIDI IN display routine later
void workscreen()
{
  // Display default MIDI channel read from EEPROM
  oled.clearDisplay();
  oled.fontsize=3;
  print(t3);
  oled.printChar(EEPROM[18] < 10 ? ' ' : '1');
  oled.printChar(0x30 + EEPROM[18] % 10);
  oled.fontsize=1;
  oled.printChar('A',0,3);
  oled.printChar('B',0,5);
  RefreshFlag = true; 
}

/********************************************** Button and Wheel handling ********************************************/
//
// Using the Bounce2 library - this library samples the attached buttons with a timestamp, and locks out changes
// within a pre-defined time window (5-10ms). It also offers edge detections via the rose() and fell() methods. 
// Reading the wheels is adjusted for type - centered pitch wheel, or uncentered mod wheel? - and adjusted for offset
// and deadband. 

Bounce button1 = Bounce();
Bounce button2 = Bounce();
Bounce button3 = Bounce();


int readWheel(int a, int  delta, boolean centered)
// Reads analog port and adjusts for calibration value delta
// I keep that one simple: The potentiometers in the wheel box
// have about just a bit more than a quarter of the full range to turn. 
// So I am assuming a maximal range of 256 (of the maximal 1024-value range)
// which allows for a simple division to get the output value.
// 
// Adjusted for the deadband constant defining the zone which is read as 0
//  
// If it is a pitch wheel (centered = true), return signed 8-bit value,
// if it is a mod wheel (centered = false), return 7-bit positive value
{
  int v = analogRead(a) - delta;
  if (centered)
  {
    // Assuming the pot normally covers just a bit more than 256 values-
    // and that center really means the middle value of the range
    
    if (v > 0)
    {
      if (v < deadband) v = 0; else v -= deadband;
      if (v > 127) v = 127;       // clip upper band 
    } else { // v < 0
      if (v > -deadband) v = 0; else v += deadband;
      if (v < -128) v = -128;       // clip lower band
    } // if (v > 0)
    // No division necessary here
  } else { // not centered
    if (v < deadband) v = 0; else v -= deadband; 
    if (v > 255) v= 255; 
    v >>= 1; // divide by two
  }
  return v;
}

/********************************************** Parameter and NON-VOLATILE RAM (NVR) HANDLING ***********************************************/
// i.e.: EEPROM Read/Write Routines

// These are the default values to be written to EEPROM memory if there is nothing sensible yet. 

const byte nvrInits[32] = {
  0,  //CHKSUM
  128,  //WheelA CC (0x80=Pitch Bend)
  1,  //WheelB CC
  64, //SwitchA CC
  128, //SwitchB CC (0x80 = ATO)
  64, //SwitchC CC
  05, 02, //WheelA Delta -> 517
  
  146, 02,  //08 WheelA Center = 658
  0, 01,  //10 WheelA Hi = 256
  188, 02,  //12 WheelB Lo = 700
  241, 03,  //14 WheelB Center = 909

  0, 01,  //16 WheelB Hi = 256
  1,    // 18 TX Default Channel
  64,   // 19 ATO Default Value
  0,    // 20 MIDI Thru
  10,    // 21 Deadband width
  0,0,
  
  0,0,0,0,
  0,0,0,0   //unused
};

#define CHKSUM_OK 0x3A //Arbitrary value you won't find in the EPROM by accident


// Build checksum by adding all bytes 
byte nvrChksum() 
{
  byte chksum = 0; 
  // chksum is simple add
  for (int i = 1;i<32;i++)
  {
    chksum += EEPROM[i];
  }
  return chksum - CHKSUM_OK;      
  // Substract the predefined constant - what you get from this is then stored in EEPROM[0] as chksum.
  // I.e., if EEPROM is valid, these conditions must apply: 
  // EEPROM[0] == nvrChksum()
}

void nvrUpdate(byte i, byte v)
{
  // Write updated value to EEPROM and adapt checksum)
  if (EEPROM[i] != v)
  {
    EEPROM.write(i,v);
    EEPROM.write(0,nvrChksum());     
  }
}

// Declare calibrate() to be able to use it
void calibrate(void);

void nvrInit()
// Write default values to NVRAM
{
  for (int i=1;i<32;i++)
  {
    EEPROM.write(i,nvrInits[i]);
  }
  EEPROM.write(0,nvrChksum()); // Set correct chksum to indicate that EEPROM is valid now
  // nvrInit() is usually called on the very first run of the hardware.
  // So let's ask the user for configuration settings (or at least calibrate the wheels): 
  calibrate();  
}

/************************************** Calibration and menu ***************************************************/

void calibrate()
// Set the offset/center value for the wheels, and try to discern a deadband range
{
  // TODO
  oled.clearDisplay();
  oled.fontsize = 1;
  oled.invert(true); 
  print(c0);
  oled.invert(false);
  print(c1);
  print(c2);
  print(c3);
  print(c4);
  print(t2);
  oled.invert(true);
  oled.fontsize=2;
  oled.setCursor(6,6);
  print(c5);
  while(!(button2.update()&& button2.fell())) /*wait for keypress*/ ;
  oled.clearDisplay();
  oled.fontsize = 2;
  wheel_a_center = analogRead(WHEEL_A);
  wheel_a_delta = wheel_a_center - 128;
  nvrUpdate(8,wheel_a_center % 256);
  nvrUpdate(9,wheel_a_center / 256);
  nvrUpdate(6,wheel_a_delta % 256);
  nvrUpdate(7,wheel_a_delta / 256);
  oled.printHex(EEPROM[7]);
  oled.printHex(EEPROM[6]);
  oled.printChar('\n');
  oled.printHex(EEPROM[9]);
  oled.printHex(EEPROM[8]);
  oled.printChar('\n');
  wheel_b_delta = analogRead(WHEEL_B);
  wheel_b_center = wheel_b_delta + 128;
  nvrUpdate(12,wheel_b_delta % 256);
  nvrUpdate(13,wheel_b_delta / 256);  
  oled.printHex(EEPROM[13]);
  oled.printHex(EEPROM[12]);
  oled.printChar('\n');
  nvrUpdate(14,wheel_b_center % 256);
  nvrUpdate(15,wheel_b_center / 256);  
  oled.printHex(EEPROM[15]);
  oled.printHex(EEPROM[14]);
  while(!(button2.update()&& button2.fell())) /*wait for keypress*/ ;
  return;
} 



void menu()
// User input of the parameters - usually called by double-klicking button 1.
// You step through the options with button 1, and set them with the right wheel or button 2. 
{
  oled.clearDisplay();
  oled.fontsize=1;
  oled.invert(true);
  print(m0);
  print(VERSION);
  oled.invert(false);
  oled.setCursor(0,1);
  print(t2);
// Crude but effective - 6 preformatted lines of text 
  print(m1);
  print(m2);
  print(m3);
  print(m4);
  print(m5);
  print(m6);
  int m= 10; // Variable keeps Where are we in the menu?
  boolean wheelMoved = false; 
  int wheelOld = readWheel(WHEEL_B,wheel_b_delta,false);
  for(;;)   // Loop until returning from routine
  {
    button1.update();
    button2.update();
    // Determine if wheel has moved; if yes, set flag
    int v = readWheel(WHEEL_B,wheel_b_delta,false);
    if (!wheelMoved)    // If wheel hasn't been moved yet
      wheelMoved = ((v - wheelOld) > 10) || ((wheelOld - v) > 10);
        
    // Stepping through the display positions and print the parameters
    // If parameter is selected, press 
    for(int i = 0;i < 11;i++)
    {
      int vv;                                   // Temporary value, either read from EEPROM or from wheel
      oled.setCursor(5+((i/5)* 8), (i % 5)+3);  // Step through two columns of five rows each
      oled.invert(i == m);                      // Display inverted if selected 
      if (i<5)                                  // Display/set CC for menu selections 0..4 
      {
        vv = ((i == m) && wheelMoved) ? v+1 : EEPROM.read(i+1);            // If selected: 
        if (button2.fell() && m == i) 
        {
          vv++;
          if (vv > 128) vv = 0;  
        }
        nvrUpdate(i+1,vv);        // This does nothing if value hasn't changed
        // Replace 0x80 with matching string, either "PWH" or "ATO"
        if (vv == 128) 
          print((i>1) ? m8 : m7) ;
        else
          oled.printHex(vv);          
      }  
      switch (i) {
        case 5: // MIDI Tx Channel
        {
          vv = ((i == m) && wheelMoved) ? (v+15)/8 : EEPROM.read(18);
          if (button2.fell() && m == i) 
          {
            vv++;
            if (vv > 16) vv = 1;  
          }
          nvrUpdate(18,vv);
          oled.printHex(vv);
        } 
        break;
        case 6: // MIDI THRU
        {
          vv = ((i == m) && wheelMoved) ? (v/64) : EEPROM.read(20);
          if (button2.fell() && m == i) 
            vv = !vv;
          nvrUpdate (20,vv);
          print(vv ? m9 : ma);
        }
        break;
        case 7: // ATO
        {
          vv = ((i == m) && wheelMoved) ? v : EEPROM.read(19);
          if (button2.fell() && m == i) 
          {
            vv++;
            if (vv > 127) vv = 0;  
          }
          nvrUpdate(19,vv);
          oled.printHex(vv);           
        }
        break;
        case 8: // Deadband, 0..63
        {
          vv = ((i == m) && wheelMoved) ? (v / 2) : EEPROM.read(21);
          if (button2.fell() && m == i) 
          {
            vv++;
            if (vv > 63) vv = 0;  
          }
          nvrUpdate(21,deadband = vv);
          oled.printHex(vv);           
        }
        break;
        case 9: // Calibrate routine
          oled.printChar('G');
          oled.printChar('O');
          if (button2.fell() && m == i)
          {
            calibrate();
            menu(); // recursive call to get menu back on
            return; // Leave routine here
          }
        break;
        case 10: // Put a litte X in the upper right corner and leave if selected
        {
          oled.setCursor(15,0);
          oled.printChar('X');
          if (button2.fell() && m == i) return;
        } 
      }        
    }
    // Button 1 steps through the options
    if (button1.fell())
    {
      if (++m > 10) m = 0;       
      wheelMoved = false;
      wheelOld = v; 
    }
  }
}

/********************************************** Additional MIDI - unused **********************************************/

// Callback Routines
void handleNoteOn(byte channel, byte pitch, byte velocity)
{
  // UNUSED - doing this by hand as even with a callback routine, you'd still have to 
  // do a midiA.read() in the main loop. 

  // Try to keep your callbacks short (no delays ect)
  // otherwise it would slow down the loop() and have a bad impact
  // on real-time performance.
}

/********************************************************* Setup *****************************************************/
// The setup routine runs once when you press reset.
// It initializes communication with the display, ties the buttons to the bounce2 library, and displays a welcome screen.
// It sets up the MIDI interface and turns the MIDI library's MIDI Thru function off. 
// If EEPROM is valid, the offset values are recalled from NVR into variables, and operation commences. 
// If NVR EEPROM is corrupt, init values are written to it, and the calibrate routine is called.
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
void loop() {

  //Adjust MIDI channel, display it, and light LED when data arrives
    midi::MidiType mt;
    char md1 = 0, md2 = 0;
  if (midiA.read())
  {
    digitalWrite(LED1, HIGH);
    MidiRxCh = midiA.getChannel();
    mt = midiA.getType();
    md1 = midiA.getData1();
    md2 = midiA.getData2();
    // MIDI Thru manually - this helps in dealing with USB MIDI later on
    // Do not send MIDI Thru to USB. 
    if (EEPROM[20] != 0)  
    {
      midiA.send(mt,md1,md2,MidiRxCh);
      #ifdef HAS_USBMIDI 
      #endif
    
      digitalWrite(LED2, HIGH);
      oled.fontsize=1;
      oled.setCursor(0,7);
      oled.printHex(MidiRxCh);
      oled.printChar(' ');
      oled.printHex(mt);
      oled.printChar(' ');
      oled.printHex(md1);
      oled.printChar(' ');
      oled.printHex(md2);
    }
    if (MidiTxCh != MidiRxCh)
    {
      RefreshFlag = true;
      MidiTxCh = MidiRxCh; // Set new channel
    // Display the new channel
      oled.fontsize=3;
      oled.px=0;  
      oled.py=0;
      print(t3);
      oled.printChar(MidiRxCh < 10 ? ' ' : '1');
      oled.printChar(0x30 + MidiRxCh % 10);
    }
  }
  


  // Button A
  if (button1.update()  || RefreshFlag)
  {
    digitalWrite(LED2,HIGH);
    if (EEPROM[3] > 0x80) // Aftertouch?
    {
      midiA.sendAfterTouch(!button1.read()*EEPROM[19],MidiTxCh);
      #ifdef HAS_USBMIDI 
        midiB.sendAfterTouch(!button1.read()*EEPROM[19],MidiTxCh);   
      #endif  
    } else {
      midiA.sendControlChange(EEPROM[3],!button1.read() * 127,MidiTxCh);
      #ifdef HAS_USBMIDI 
        midiB.sendControlChange(EEPROM[3],!button1.read() * 127,MidiTxCh);
      #endif
    }
    oled.fontsize=1;
    oled.printChar(button1.read() ? ' ' : '*',12,3);
    // double click code
    if (button1.fell())
    {
      if (millis()- doubleclick < DC)
      { // Double click detected!
        menu();
        workscreen();
      }        
      else
      // Single click, save time of event and restart detection    
        doubleclick = millis(); 
    } //if button1.fell     
  }
  
  // Button B
  if (button2.update()  || RefreshFlag)
  {
    digitalWrite(LED2,HIGH);
    if (EEPROM[4] > 0x80) // Aftertouch?
    {
      midiA.sendAfterTouch(!button2.read()*EEPROM[19],MidiTxCh);
      #ifdef HAS_USBMIDI 
        midiB.sendAfterTouch(!button2.read()*EEPROM[19],MidiTxCh); 
      #endif    
    } else {
      midiA.sendControlChange(EEPROM[4],button2.read() ? 127 : 0,MidiTxCh);
      #ifdef HAS_USBMIDI 
        midiB.sendControlChange(EEPROM[4],button2.read() ? 127 : 0,MidiTxCh);
      #endif
    }
    oled.fontsize=1;
    oled.printChar(button2.read() ? ' ' : '*',12,5); 
  }
  
  // Button C (Footswitch)
  if (button3.update() || RefreshFlag)
  {
    digitalWrite(LED2,HIGH);
    if (EEPROM[5] > 0x80) // Aftertouch?
    {
      midiA.sendAfterTouch(!button3.read()*EEPROM[19],MidiTxCh);
      #ifdef HAS_USBMIDI 
        midiB.sendAfterTouch(!button3.read()*EEPROM[19],MidiTxCh);     
      #endif
    } else {
      midiA.sendControlChange(EEPROM[5],button3.read() ? 127 : 0,MidiTxCh);
      #ifdef HAS_USBMIDI 
        midiB.sendControlChange(EEPROM[5],button3.read() ? 127 : 0,MidiTxCh);
      #endif
    }
    oled.fontsize=1;
    oled.printChar(button3.read() ? ' ' : '*',12,7); 
  }  

  // Wheel A
  boolean isPitch = (EEPROM[1] > 127);
  value = readWheel(WHEEL_A,isPitch ? wheel_a_center : wheel_a_delta, isPitch);
  if ((value_wheel_a != value)  || RefreshFlag)
  {
    digitalWrite(LED2,HIGH); 
    value_wheel_a = value;
    if (isPitch)
    {
//      With v4.2 of the MIDI library, positive values only
//      midiA.sendPitchBend((value+128)*64,MidiTxCh);
//      midiB.sendPitchBend((value+128)*64,MidiTxCh);
// ...but with the most recent version of the MIDI library, V4.3:
      midiA.sendPitchBend((value)*64,MidiTxCh);
      #ifdef HAS_USBMIDI 
        midiB.sendPitchBend((value)*64,MidiTxCh);
      #endif
    } else {
    // Send MIDI CC
      midiA.sendControlChange(EEPROM[1] % 0x7f,value,MidiTxCh);
      #ifdef HAS_USBMIDI 
        midiB.sendControlChange(EEPROM[1] % 0x7f,value,MidiTxCh);  
      #endif
    }
    
  // Display code
    oled.fontsize = 2; 
    oled.setCursor(4,3);
    oled.printHex(value); 
  }

  // Wheel B
  isPitch = (EEPROM[2] > 127);
  
  value = readWheel(WHEEL_B,isPitch ? wheel_b_center : wheel_b_delta, isPitch);
  if ((value_wheel_b != value)  || RefreshFlag)
  {
    digitalWrite(LED2,HIGH); 
    value_wheel_b = value;
    if (isPitch)
    {
      midiA.sendPitchBend(value*64,MidiTxCh);
      #ifdef HAS_USBMIDI 
        midiB.sendPitchBend(value*64,MidiTxCh);
      #endif
    } else {
    // Ignore ATO for the moment
      midiA.sendControlChange(EEPROM[2] % 0x7f,value,MidiTxCh);
      #ifdef HAS_USBMIDI 
        midiB.sendControlChange(EEPROM[2] % 0x7f,value,MidiTxCh);  
      #endif
    }
    
  // Display code
    oled.fontsize = 2; 
    oled.setCursor(4,5);
    oled.printHex(value); 
  }
  
  //Clean up
  RefreshFlag = false;
  digitalWrite(LED1, LOW);
  digitalWrite(LED2, LOW);
}

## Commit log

2017-09-15 Preliminary version of the Teensy sketch
    ...missing large parts of the menu and the calibration routine. More soon.
2017-09-19 Add files via upload
    Updated to version 0.4:
    - Adjustable deadband
    - Bounce2 debounce library
    - Detect double click to call menu
    V0.3:
    - Menu routine to configure EEPROM parameters
    - Negative characters (white background)
    V0.2:
    - Generalized Wheel and Button handling routines (no hard-coded CC)
    - MIDI Thru parameter
    - LEDs fixed: LED1 signals MIDI input, LED2 signals MIDI output (w/o thru)
2020-02-04 Uploaded v0.6
    Using the PlatformIO environment now; it should compile fine in the Arduino/Teensyduino IDE though.
2023-03-25 Update main.cpp
    Fixes by Dan Lavin
    [main.cpp]
2026-03-19 Add design spec for CircuitPython port to Raspberry Pi Pico 2
    Spec covers: modular HAL architecture, MIDI merge (USB Host + DIN),
    JSON config system, on-device menu, MAX3421E USB Host for Launchpad
    Pro 3 input, DIN MIDI output to Roland SE-02.
2026-03-19 Add implementation plan for CircuitPython Pico 2 port
    13-task plan covering: boot.py, pins, config, LEDs, buttons, wheels,
    display, UART MIDI, USB Host MIDI, merge engine, calibration, menu,
    and main loop integration.
2026-03-19 feat: add boot.py and pins.py foundation for CircuitPython port
2026-03-19 feat: add ConfigManager with JSON config, defaults, and validation
    Implements ConfigManager in circuitpython/lib/config.py with dot-notation
    get/set, recursive merge-over-defaults on load, range clamping validation,
    and silent error handling for read-only filesystems. Adds circuitpython/config.json
    as the on-device default configuration file. No CircuitPython-specific imports
    used — fully testable on desktop Python 3.
2026-03-19 feat: add AnalogWheel with calibration, deadband, and 14-bit pitch bend
2026-03-19 feat: add UartMidi for DIN MIDI In/Out over UART
2026-03-19 feat: add WheelCalibration interactive routine
2026-03-19 feat: add code.py main loop — complete CircuitPython port
2026-03-19 docs: add CircuitPython deployment instructions to CLAUDE.md
2026-03-20 feat: enable USB MIDI device output and bidirectional USB Host
    - boot.py: remove usb_midi.disable() so controller appears as USB MIDI device
    - New midi_usb_device.py: native USB MIDI for laptop/DAW communication
    - midi_usb_host.py: add send() for Launchpad return channel
    - midi_merge.py: refactor to dict-based outputs with echo prevention
    (messages from a source are not sent back to that same source)
    - code.py: wire all three MIDI interfaces as both inputs and outputs
    Signal flow now supports:
    Launchpad (USB Host) + DIN In + laptop (USB Device) → MidiMerge
    → DIN Out (SE-02) + USB Device (laptop) + USB Host (Launchpad)
2026-03-20 feat: make USB Host (MAX3421E) optional for laptop-only mode
    Controller now works in two configurations:
    - With MAX3421E: full merge (Launchpad + DIN + USB Device)
    - Without MAX3421E: pure USB MIDI device + DIN (laptop-only mode)
    SPI bus and USB Host are only initialized if the max3421e library
    is installed. Missing library = graceful skip, no crash.
2026-03-29 fix: resolve all 22 Pico bugs, add CP10 compat, watchdog, test harness
    Bug fixes (P1-P22 from BUGLIST_PICO.md):
    - P1: boot.py dev mode pin GP17→GP0
    - P2: "off" and "note" modes for wheels/buttons
    - P3: narrow bare Exception catches in midi_usb_host.py
    - P4: config.set() validation with clamping
    - P5: display decimal for pitch bend, hex for CC
    - P6: output LED lights for thru-forwarded messages
    - P7: menu forces wheel_b to CC mode during use
    - P8: USB host scan cooldown (500ms)
    - P9: None cc_number guard on all MIDI sends
    - P10: MIDI queue bounded at 64 messages
    - P11: calibration 30s timeout
    - P12: save failure shown on display
    - P13: corrupt config detected and reported
    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
2026-03-29 fix: display shows signed pitch bend and decimal CC values
    - Pitch bend: convert unsigned 0-16383 to signed -8192..8191 for display
    - CC mode: show decimal 0-127 instead of hex
    - Extracted _format_wheel() helper for consistent formatting
2026-03-29 fix: menu jitter redraw, wider double-click window, hardware test
    - Menu: only redraws when wheel moves >5 from last actioned position,
    preventing continuous redraw from ADC jitter
    - Double-click window: 250ms → 400ms for easier menu entry
    - New tests/test_hardware.py: interactive hardware diagnostic script
    that tests wheels, buttons, LEDs, and jitter
2026-03-29 fix: move watchdog enable to end of first successful loop iteration
    Prevents crash-loop: if code.py crashes during the first iteration,
    the watchdog isn't active yet, so the device stays at the REPL
    instead of resetting endlessly.
2026-03-29 docs: rewrite README.md for V3.0 Pico-based controller
    Complete documentation of hardware, installation, testing, known
    issues, and project structure. Documents all hardware test results
    from 2026-03-29 session including the open DIN MIDI issue.
